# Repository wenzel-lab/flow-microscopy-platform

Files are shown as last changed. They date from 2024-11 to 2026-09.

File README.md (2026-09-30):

# Rio, the open-source flow microscopy platform
Our open hardware flow microscopy platform "Rio Platform" is a more comprehensive version of our open-source [strobe-enhanced microscopy stage](https://github.com/wenzel-lab/strobe-enhanced-microscopy-stage) (build instructions [here](https://wenzel-lab.github.io/strobe-enhanced-microscopy-stage/)), including the control of pressure, flow and temperature in 4-channels. The platform is controlled by ["Rio", our modular microfluidics controller](https://github.com/wenzel-lab/modular-microfluidics-workstation-controller) boards and firmware. Working with pressurised gas, regulators, and flow sensors allows for a compact, faster, and more precise flow control compared to syringe pumps, such as our [3D printed syringe pumps with controller](https://github.com/wenzel-lab/syringe-pumps-and-controller). In contrast to other open-source platforms and some commercial platforms, our implementation is capable of handling high-pressures (up to 6 bar) in order to process gels and more viscous liquids.

Follow us! [#twitter](https://twitter.com/WenzelLab), [#YouTube](https://www.youtube.com/@librehub), [#LinkedIn](https://www.linkedin.com/company/92802424), [#instagram](https://www.instagram.com/wenzellab/), [#Printables](https://www.printables.com/@WenzelLab), [#LIBREhub website](https://librehub.github.io), [#IIBM website](https://ingenieriabiologicaymedica.uc.cl/en/people/faculty/821-tobias-wenzel)

## Usage

<p align="left">
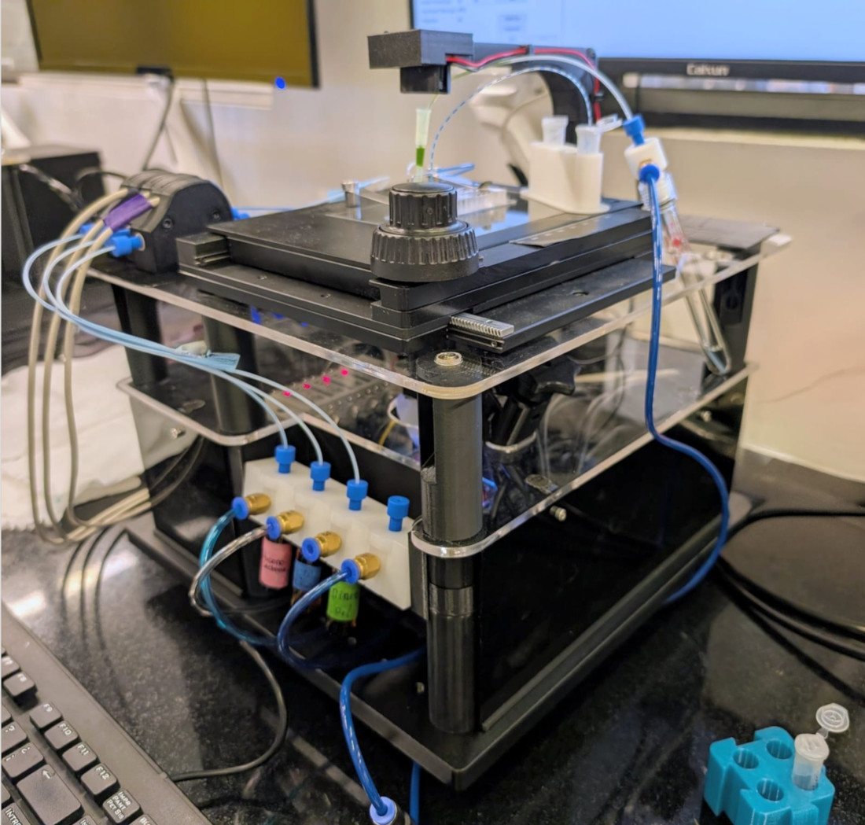
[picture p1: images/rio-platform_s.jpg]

</p>

The platform consists of a number of different functional modules that are connected to each other:
<p align="left">
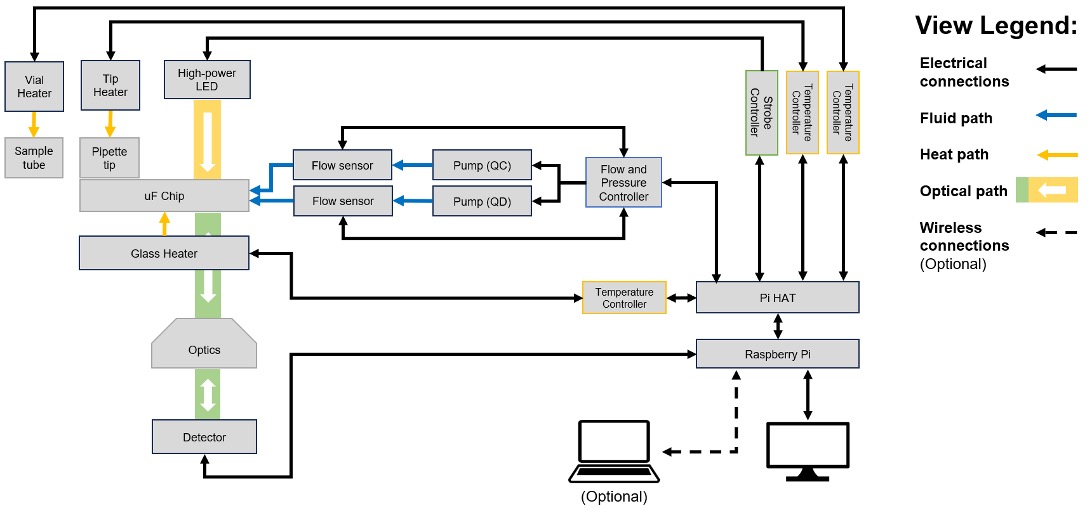
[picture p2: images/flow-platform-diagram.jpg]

</p>

One use of our heater modules is the tip-heater for injecting agarose gel into microfluidic chips:
<p align="left">
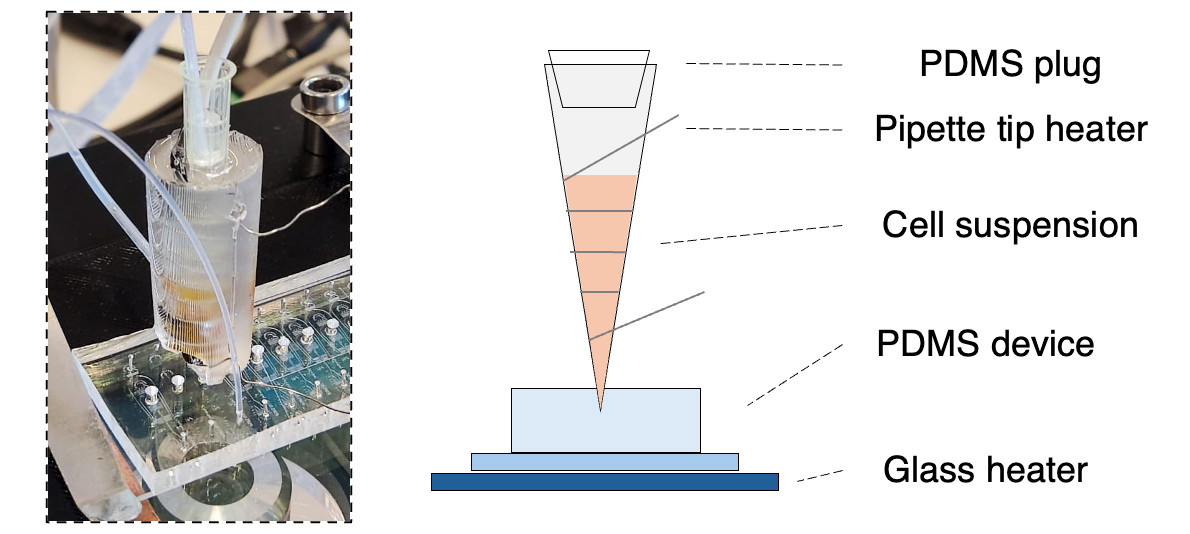
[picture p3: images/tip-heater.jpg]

</p>

We also designed a pressure vial holder with individual manifold caps for easy transfer of samples:
<p align="left">
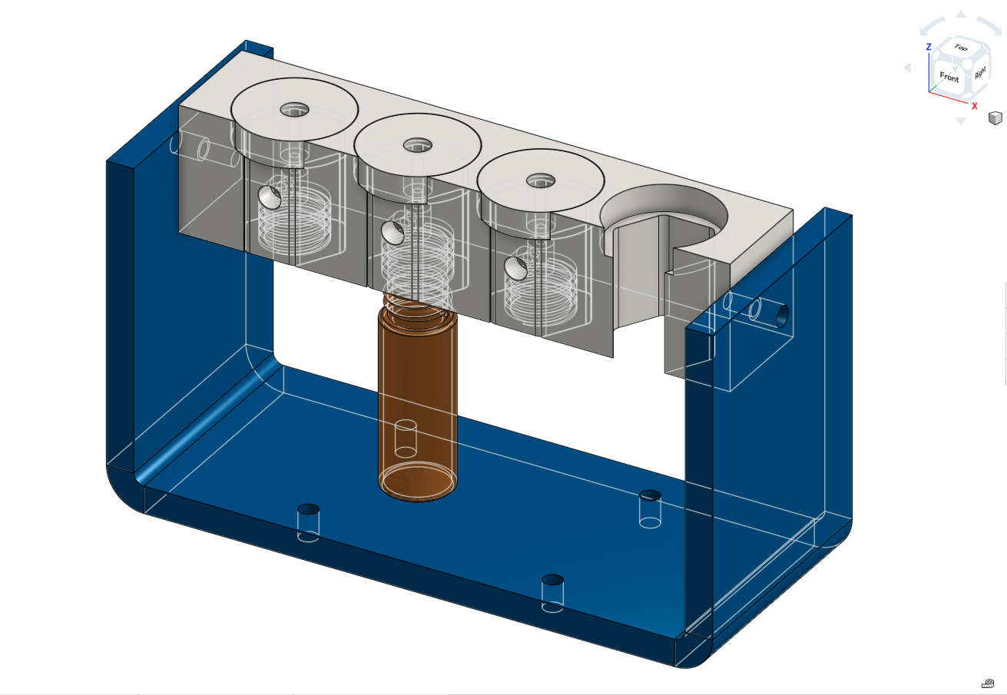
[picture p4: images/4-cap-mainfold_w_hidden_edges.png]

</p>

We also implemented a droplet detection AI module to measure the droplet diameters and display the size distribution https://github.com/wenzel-lab/droplet_AInalysis

## Contribute

You're free to fork the project and enhance it. If you have any suggestions to improve it or add any additional functions make a pull-request or [open an issue](https://github.com/wenzel-lab/flow-microscopy-platform/issues/new).
For interactions in our team and with the community applies the [GOSH Code of Conduct](https://openhardware.science/gosh-2017/gosh-code-of-conduct/).

## Team

+ Project initiators:
    - Tobias Wenzel @MakerTobey
    - Christie Nel @Cyberius
    - Pierre Padilla-Huamantinco @biodotpe
    - Matias Hurtado @matiashl27
+ Contributors:
    - Eduardo Honeyman

## License

[CERN OHL 2W](LICENSE) © Tobias Wenzel, Christie Nel, Eduardo Honeyman, Matías Hurtado, and Pierre Padilla-Huamantinco. This project is Open Source Hardware - please acknowledge us when using the hardware or sharing modifications.

## Funding

This work is part of funded projects granted to T.W. from ANID FONDECYT Iniciacion 11200666, the Chang Zuckerberg Initiative project ‘Latin American Hub for Bioimaging Through Open Hardware’, and CIFAR. Our team is also grateful for the additional funding and resources provided by the [Institute for Biological and Medical Engineering](https://ingenieriabiologicaymedica.uc.cl/en/).

# This project is documented with GitBuilding

## What is GitBuilding

GitBuilding is an OpenSource project for documenting hardware projects with minimal
effort, so you can stop writing and GitBuilding. GitBuilding is a python program that
works on Windows, Linux, and MacOS. More information on the GitBuilding project, or how
to install GitBuilding please see the [GitBuilding website](http://gitbuilding.io)

## How do I edit the documentation?

To edit the documentation you do not need to install anything, the documentation files can
be opened in a plain text editor such as Windows Notepad, Notepad++, gedit, VS Code, etc.
We recommend installing GitBuilding to preview any changes to the documentation.
GitBuilding also comes with a browser-based editor that has a live display of the final HTML documentation.

If you have ever used [markdown](https://www.markdownguide.org/basic-syntax/) you will
notice that the files you are editing are markdown files. GitBuilding uses an extended
markdown syntax (that we call BuildUp). This allows you to keep track of parts in the
documentation. More detailed documentation is available on the
[GitBuilding website](https://gitbuilding.io).

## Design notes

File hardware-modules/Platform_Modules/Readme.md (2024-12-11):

## Organization Modules 
Here you can find information about the different modules created to organize the flow microscopy platform, 3D files are all free accces on Onshape [here](https://cad.onshape.com/documents/959fee0bf6a5bfe78f1dda97/w/e657b641acef5b36bf9099ee/e/20e65f96ae81a38be57a4961)

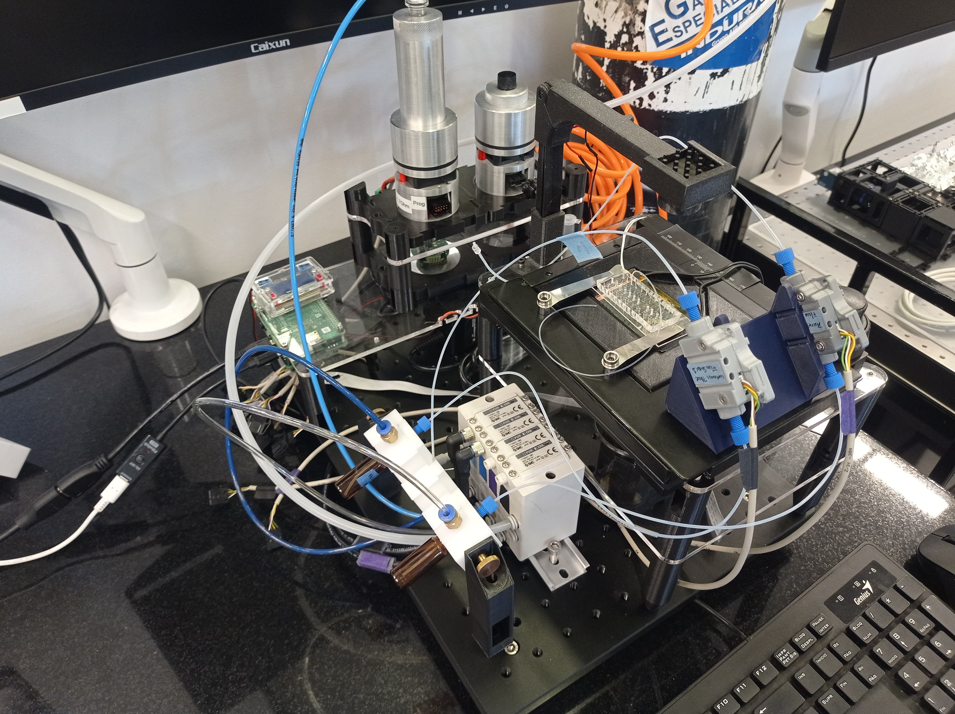
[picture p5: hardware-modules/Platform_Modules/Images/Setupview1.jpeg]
 
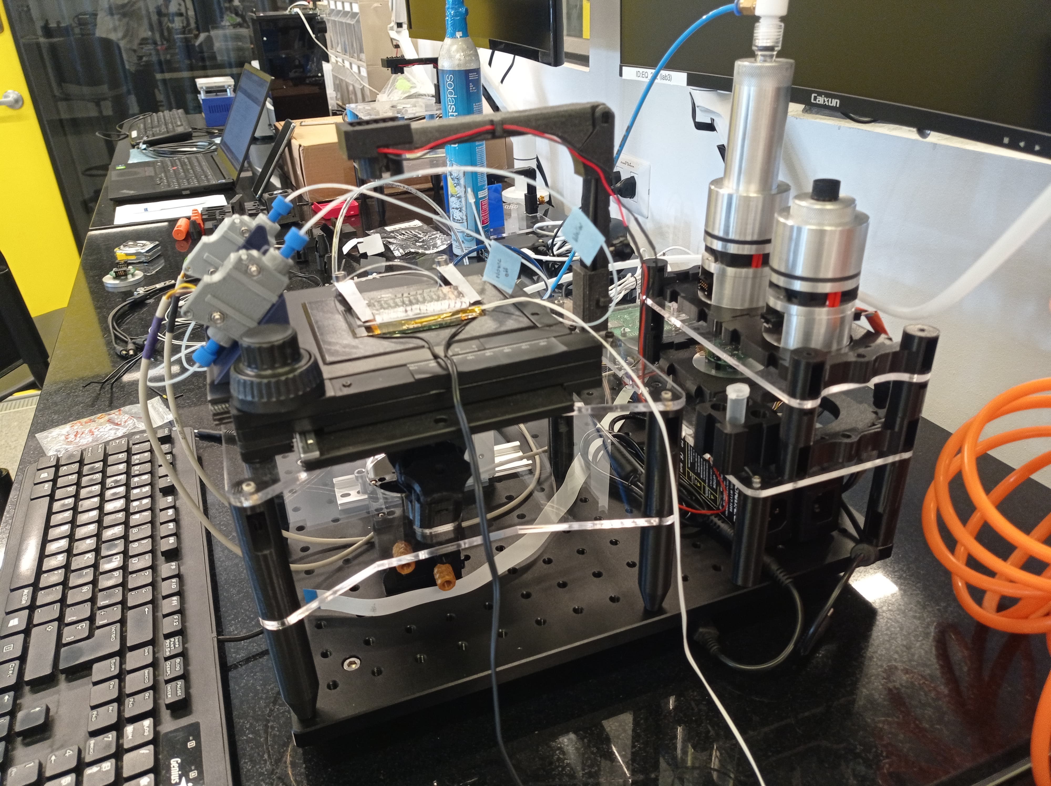
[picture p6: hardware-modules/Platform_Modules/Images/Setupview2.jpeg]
 

From the analysis of the state of the microscopy platform without a clear method of organization eight crucial modules were identified:
- Pressure module
- Flow module
- Vial heat and stir module
- Glass heater module
- Tip heater module
- High-speed imaging module 
- Vial holder module 
- Electronic control module
  
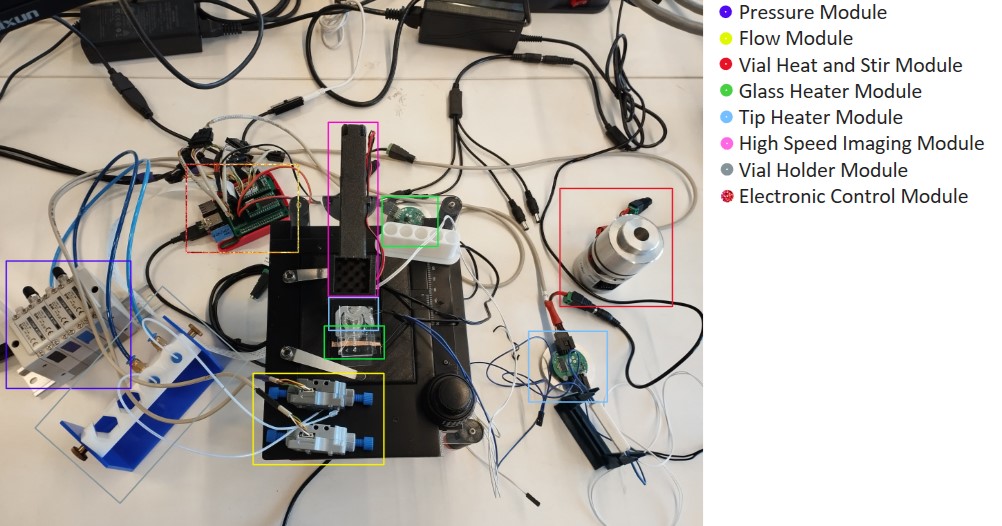
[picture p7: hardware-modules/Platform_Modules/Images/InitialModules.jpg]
 

In that state, all the modules were using an unreasonable amount of space in the science lab, therefore the objective of adapting them to an enclosed space and improving the organization and clustering of cables while maintaining the functionality of the system was established. To direct this process the established area was limited by an optic table with dimensions of 30 by 40 centimeters, which was purchased [here](https://es.aliexpress.com/item/1005005133684496.html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). The reason to use this table is that it allows for an easier fixing of the elements to it do to the high weight and screwable surface.

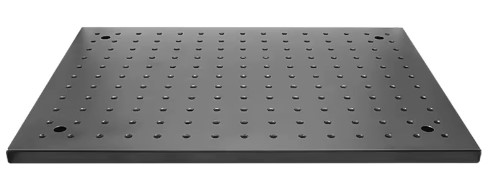
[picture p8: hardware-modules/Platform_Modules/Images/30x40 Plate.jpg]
 

From the eight initial modules we decide on reducing them to five by joining the modules that benefit for beeing closer together, resulting in this first iteration.

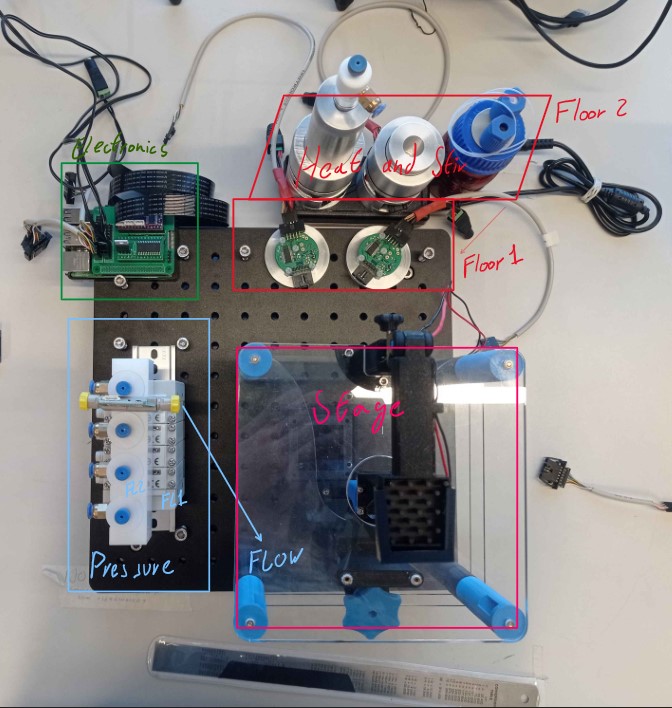
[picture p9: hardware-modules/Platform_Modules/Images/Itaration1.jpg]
 

From further iteration on this model we got to the final optimal organization moduls that you can find with greater detail here:
- [Brain Module (Electronics)](Brain_Module/Readme.md)
- [Heat and Stir Module](Heat_Stir_Module/Readme.md)
- [Pressure Regulator Module](Pressure_Module/Readme.md)
- [Flow Sensor Module](Flow_Module/Readme.md)
- [Stage Module](Stage_Module/Readme.md)

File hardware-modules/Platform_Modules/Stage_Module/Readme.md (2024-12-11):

## Microscopy Stage Module

This includes all the components that conform to the microscopy stage, like the microscope, movements stage, stage legs, and leg adaptors for the optic table

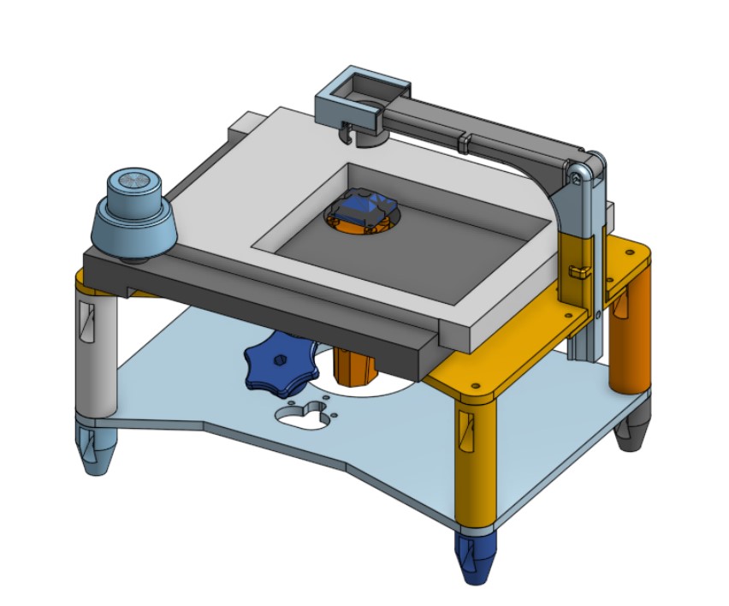
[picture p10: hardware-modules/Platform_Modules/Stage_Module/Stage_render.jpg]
 
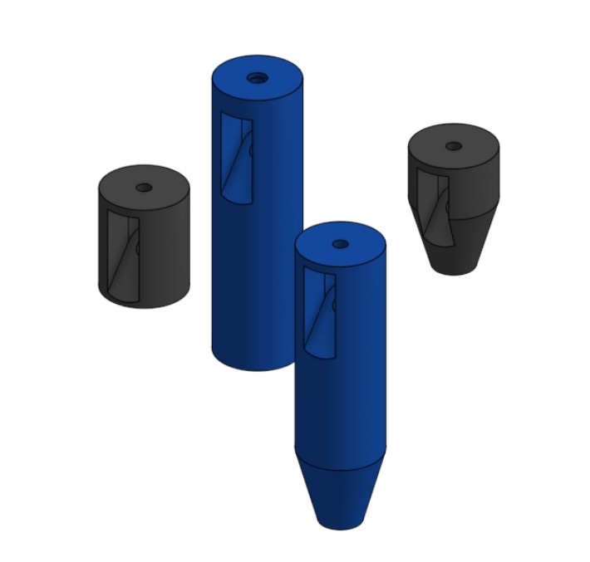
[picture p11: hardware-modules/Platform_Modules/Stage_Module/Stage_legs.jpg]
 
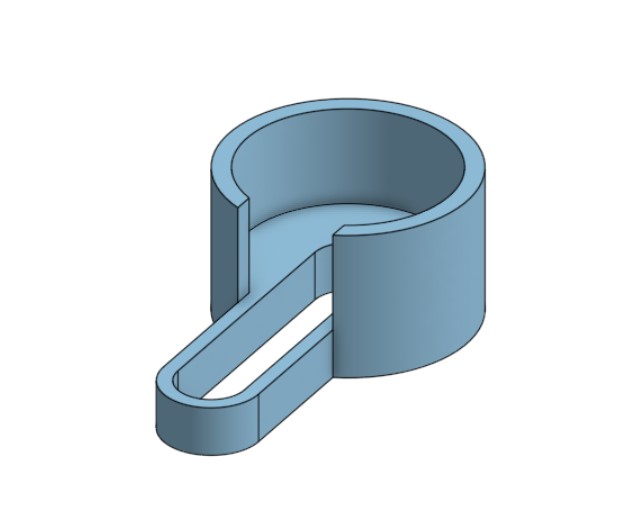
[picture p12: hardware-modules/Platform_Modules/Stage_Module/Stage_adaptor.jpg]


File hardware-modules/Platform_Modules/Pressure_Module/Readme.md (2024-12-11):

## Pressure Regulator Module

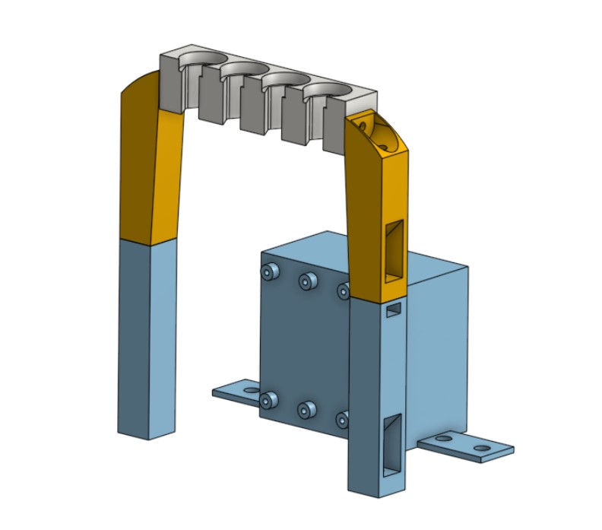
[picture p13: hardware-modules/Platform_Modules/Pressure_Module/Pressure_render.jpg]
 

One of the crucial components when it comes to microfluidics experimentation is the correct management of the pressure of the fluids, for this a pressure regulator is needed

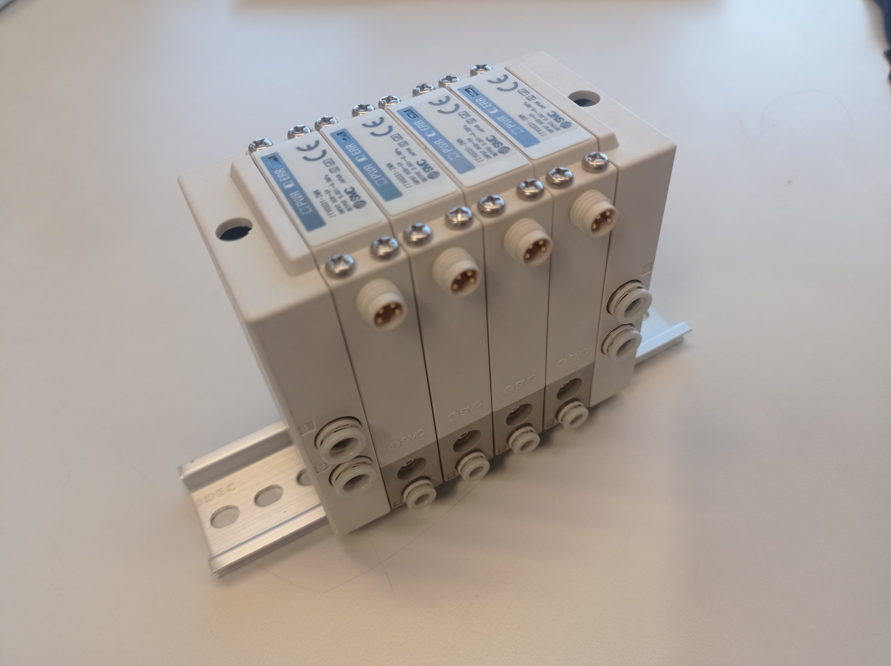
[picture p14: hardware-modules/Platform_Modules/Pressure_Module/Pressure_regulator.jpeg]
 

This regulator connects directly to the fluid samples that in the early unorganized state were held by the sample reservoir you can find [here](flow-microscopy-platform/module_sample_reservoirs/Readme.md).

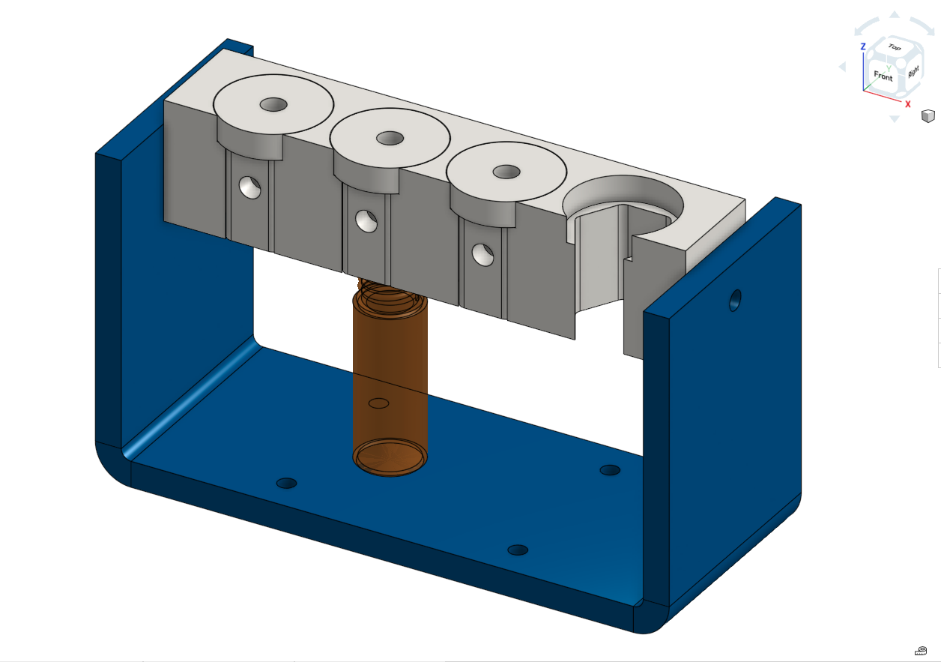
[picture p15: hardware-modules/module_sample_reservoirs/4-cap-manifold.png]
 

To accommodate the regulator and the samples in the newly organized setup the first step was allowing them to be closer to each other and reduce the need for unnecessary tubings between them. To prevent the reservoirs from crashing with the regulator new legs for de sample reservoir were designed allowing to modularly change of the height of the holder depending on the position of the regulator another component of the microscopy stage.

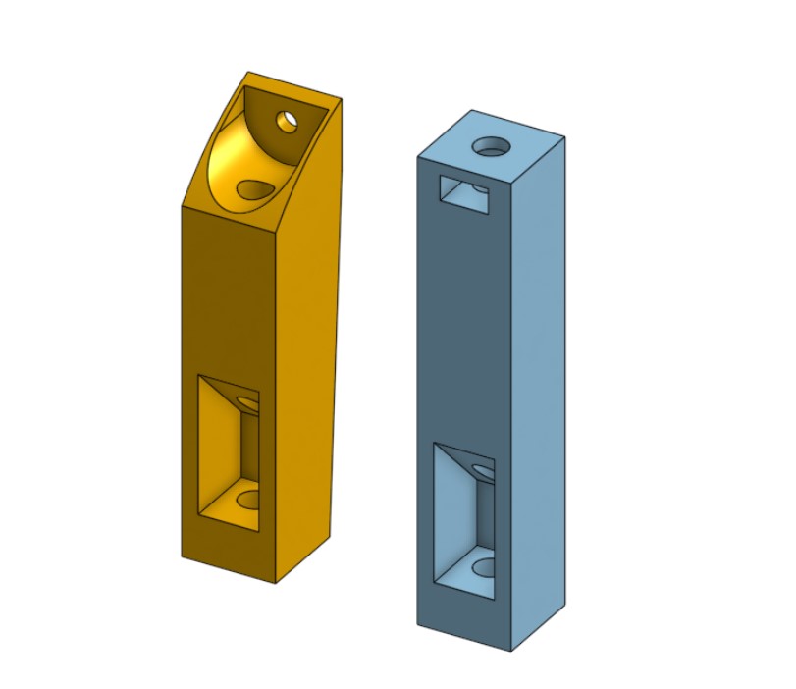
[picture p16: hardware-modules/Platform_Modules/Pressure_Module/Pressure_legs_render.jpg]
 
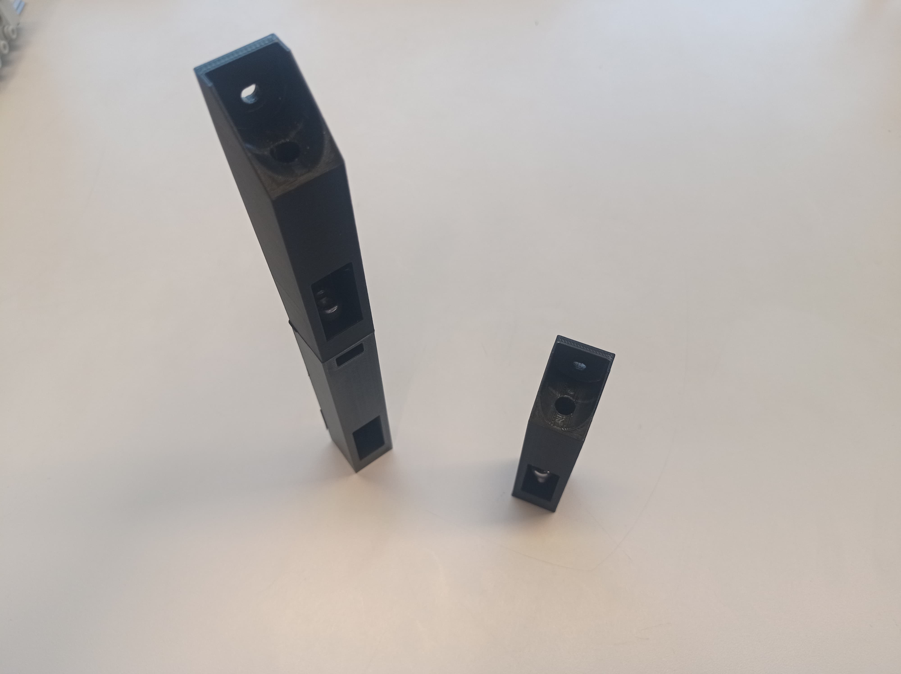
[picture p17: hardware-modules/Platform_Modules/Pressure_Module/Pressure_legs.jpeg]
 
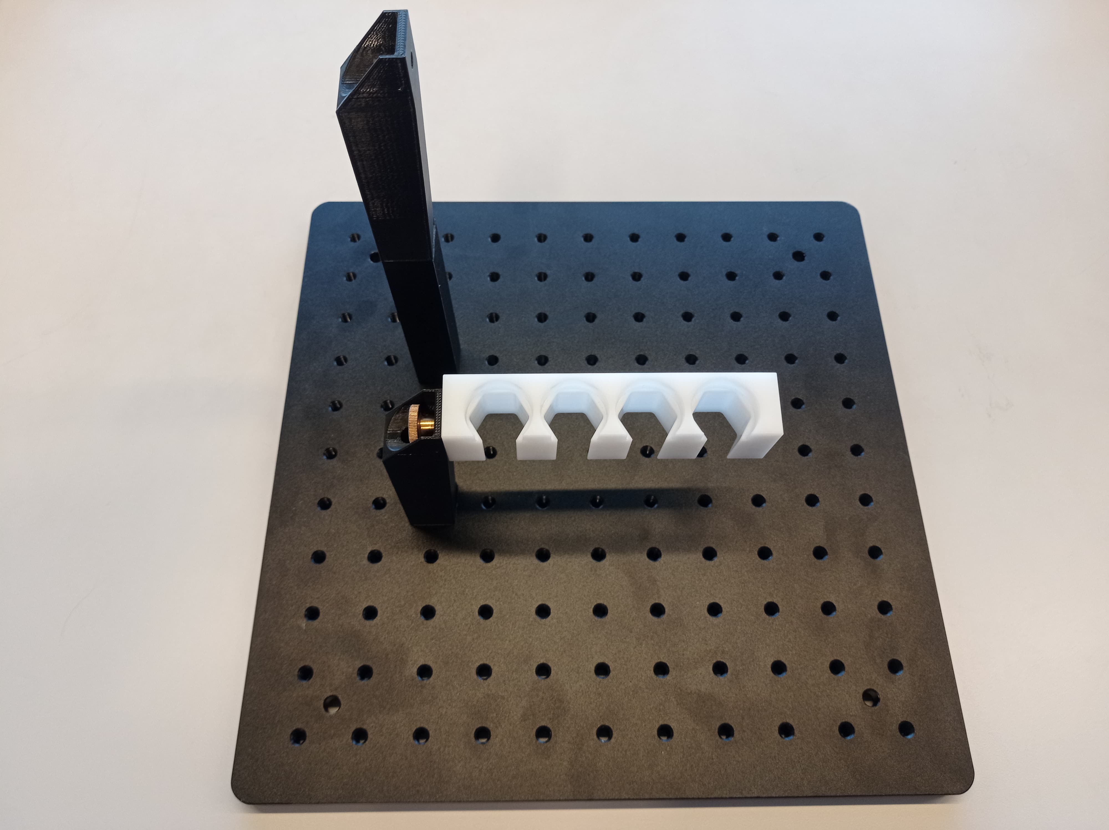
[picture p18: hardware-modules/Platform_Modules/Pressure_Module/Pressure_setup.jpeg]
 

both the new legs and the regulator allow for a simple M6 screw to hold them onto the optic table but a screw and nut are needed for the extra levels of the legs

### Future Steps
- Is in discussion the need to use an external component to hold the vials and as a possibility using lacer cuts to hold the samples onto the plates of the microscope is a viable option
- The use of longer legs is determined by the height of the position of the flow controllers and is possible to need adjustments if the position of the flow controller changes
- The regulator is optimal to be closer to the samples but it's not completely necessary for both to be in the same vertical position and there is room to improve on changing the horizontal angle between these two components

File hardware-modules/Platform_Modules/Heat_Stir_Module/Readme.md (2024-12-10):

## Heat and Stear Module
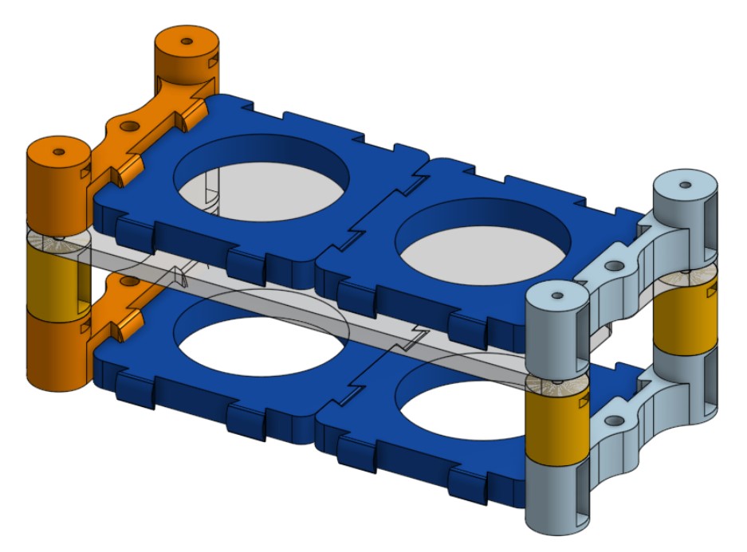
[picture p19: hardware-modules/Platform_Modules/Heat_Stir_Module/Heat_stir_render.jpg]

For instance, the microfluid stage needs to be heated or the sample needs to be stared while kept warm, for this there is the need for 2 heaters and stirring components.

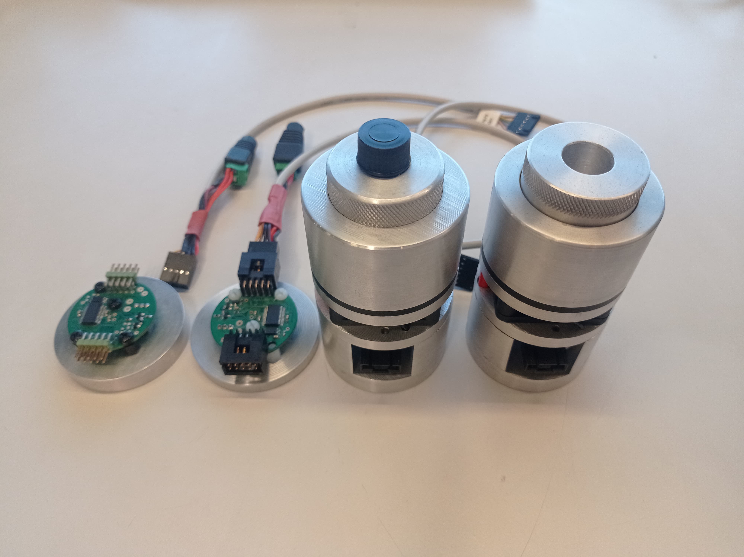
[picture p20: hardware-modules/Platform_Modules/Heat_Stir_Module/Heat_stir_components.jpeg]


These components share the same base, a 5.5 cm diameter metal plate, for this a modular system that allows these 4 components to be enclosed together while minimizing space was implemented. This works with base pillars that have a design compatible with the [Modular Tube Holders](https://www.printables.com/model/514591-moldular-tube-holders) used by LibreHub, and that using the same stage legs from the microscopy stage allows for the assembling of multiple  floors  using an acrylic plate of 5 or 6 mm as support.

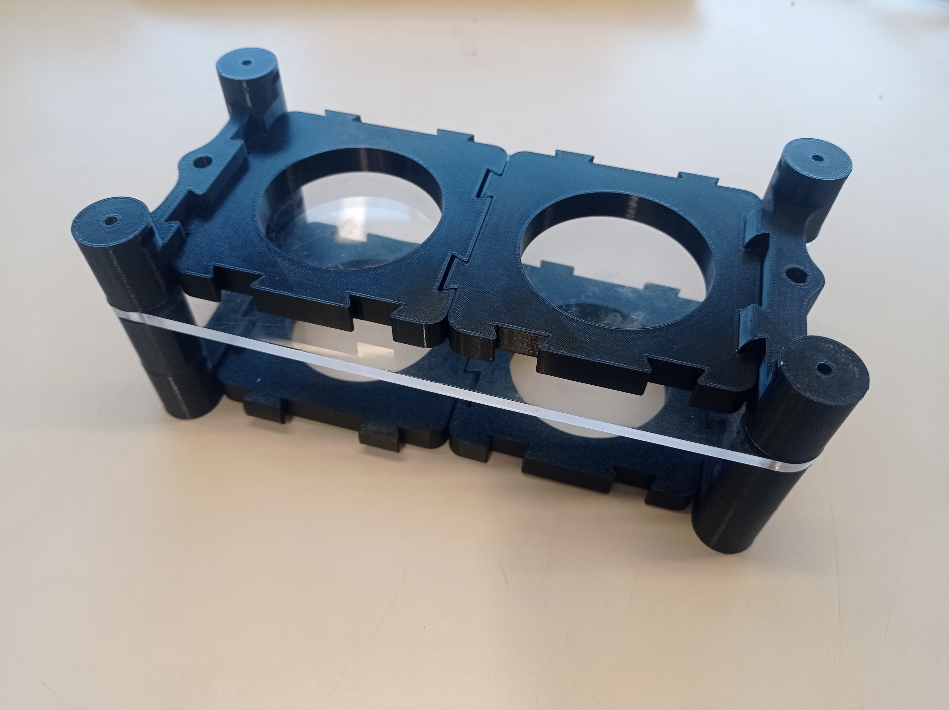
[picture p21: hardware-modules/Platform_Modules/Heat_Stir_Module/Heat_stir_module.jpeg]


This module can be set up on top of the [Brain module](Platform_Modules/Brain_Module/Readme.md) connecting the stage legs or set up directly onto the optic table using the corresponding M4 screws

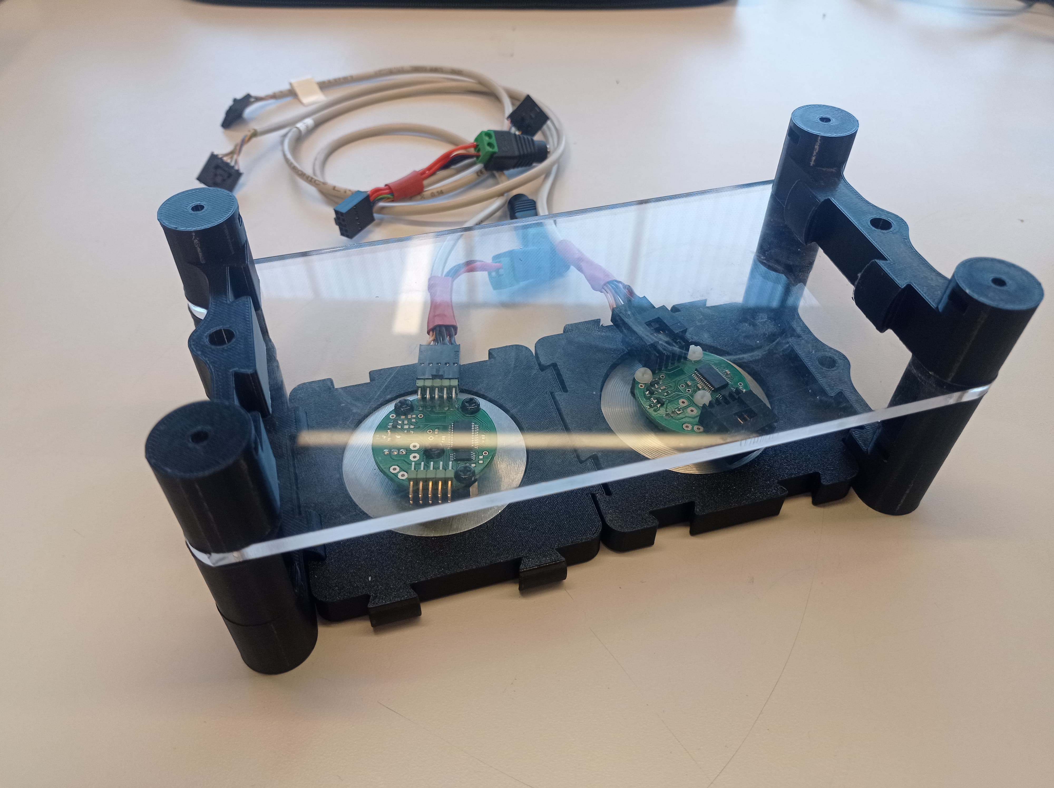
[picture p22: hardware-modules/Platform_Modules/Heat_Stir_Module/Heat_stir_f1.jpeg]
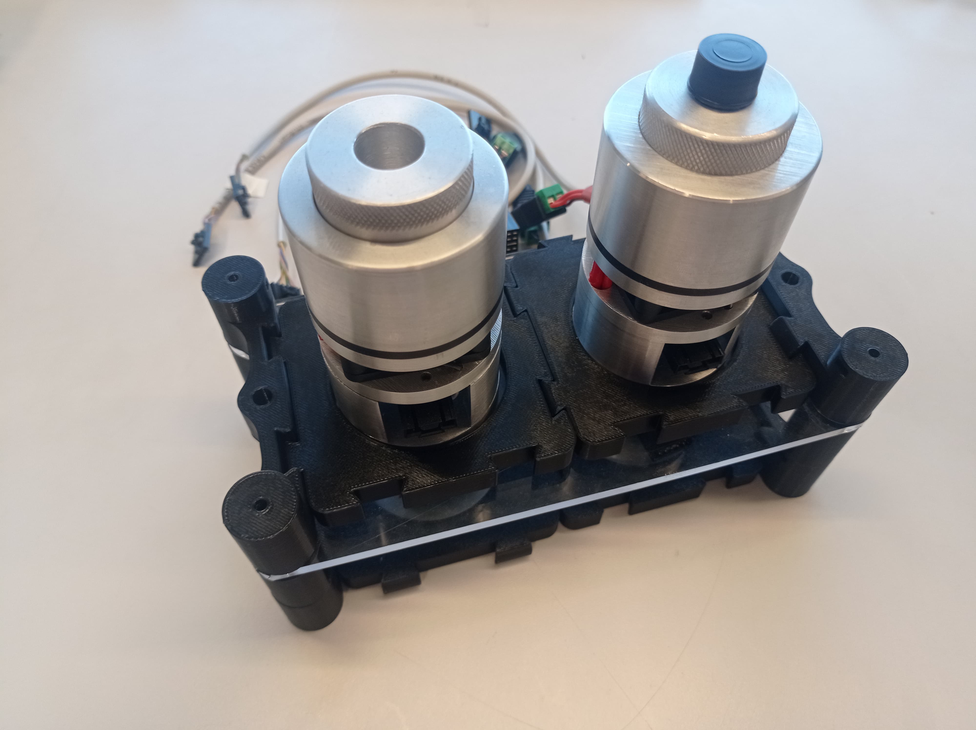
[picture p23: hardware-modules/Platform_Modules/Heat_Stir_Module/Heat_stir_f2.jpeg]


### Future Steps:
- The height of this stage could be modified so the second floor is on the same level as the microscopy stage
- Because the brain stage was designed later there is space on the surface of it that could be used by extending the bases of this module and allowing for extra tube holders

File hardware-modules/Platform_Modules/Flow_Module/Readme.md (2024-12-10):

## Flow Sensor Module
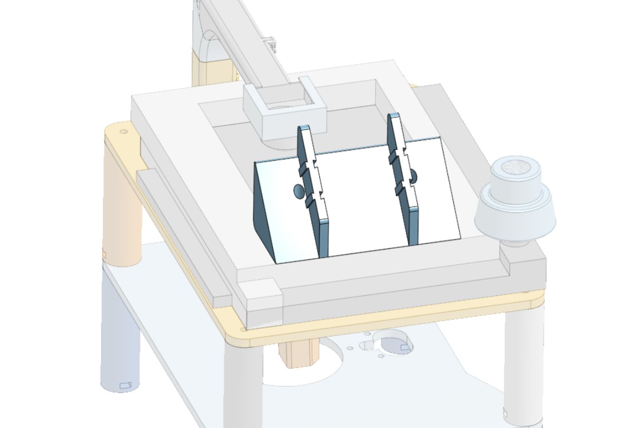
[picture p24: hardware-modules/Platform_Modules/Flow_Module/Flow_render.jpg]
 

This module consists of a 3D printed holder for the flow controllers whose objective is to keep the controllers still and close to the microchip of microfluidics allowing the tubings that run in between them to not be altered and as benefits shorten the time of travel from controller to chip.

The holder module is designed to be compatible with the flow controller casing previously designed to protect them. Working with a slide mechanism allows for easy handling of the flow controllers while maintaining a firm grip on them. this puts together is meant to be screwed into a metal [x-y movement system](link to stage module or web page of the system) using short M2 screws, this movement system is mounted to the microscopy stage to improve the observation of samples, more details [here]("Platform_Modules/Stage_Module/Readme.md")

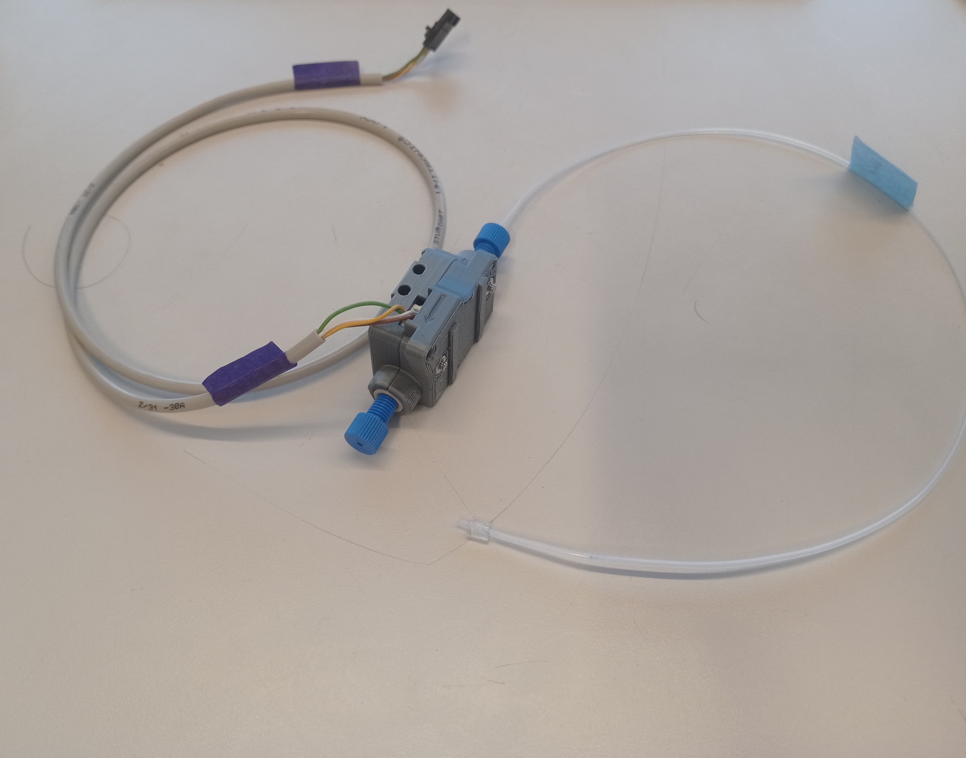
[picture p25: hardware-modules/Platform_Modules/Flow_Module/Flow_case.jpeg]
 
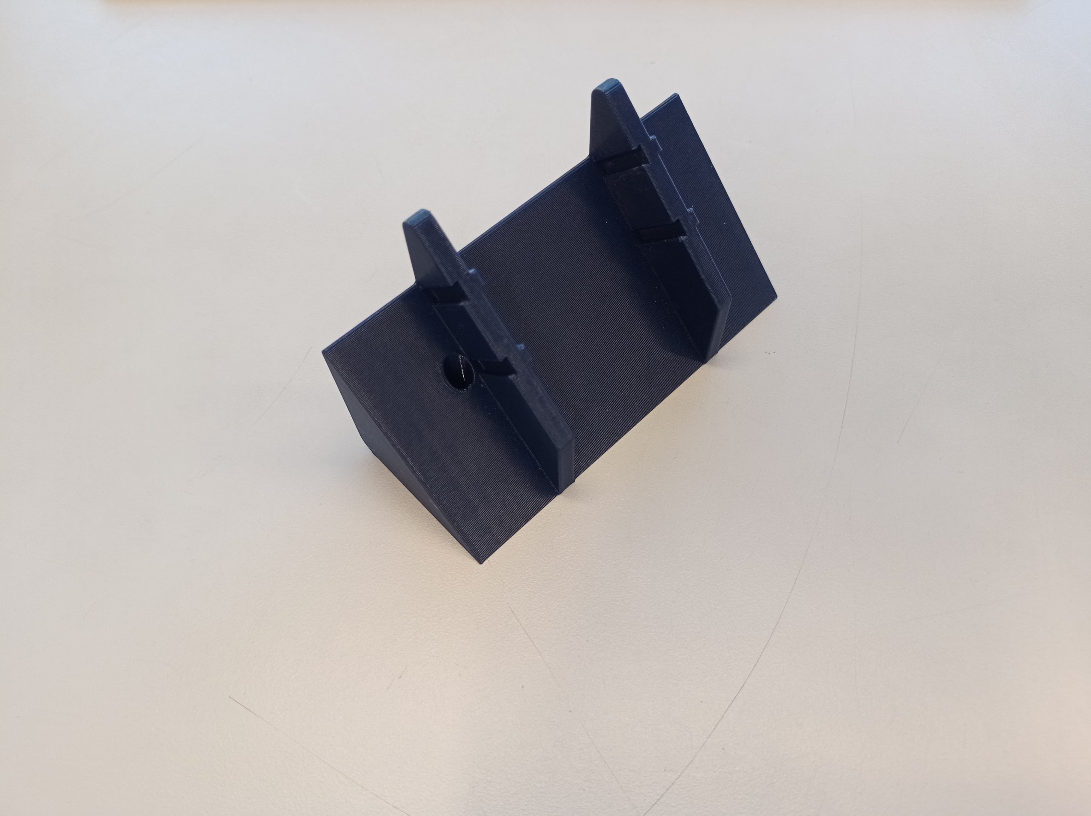
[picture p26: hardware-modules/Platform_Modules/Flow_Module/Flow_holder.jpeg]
 
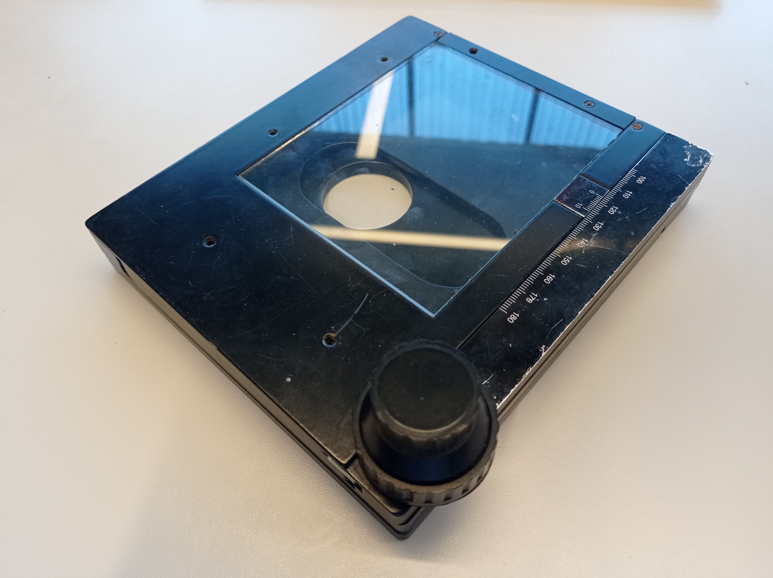
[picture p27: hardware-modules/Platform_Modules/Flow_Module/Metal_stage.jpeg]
 
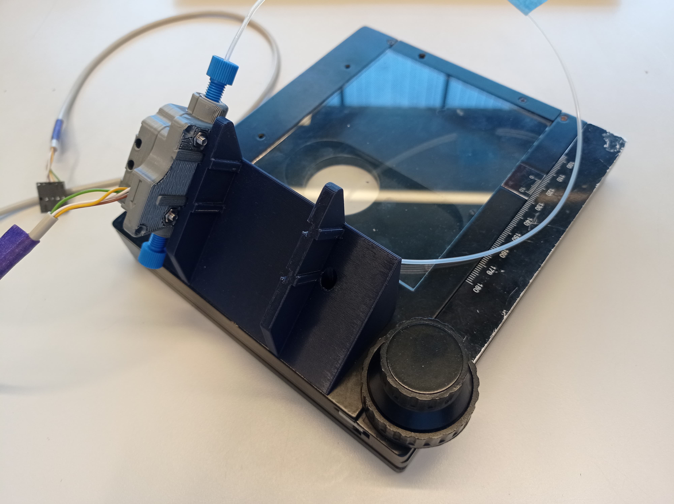
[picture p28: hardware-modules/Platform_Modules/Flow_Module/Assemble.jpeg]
 

### Future Steps
- The holder was tested on a horizontal position but proved not efficient for being too close to the microchip, the angle of inclination of the holder could be adjusted to improve on this
- At the moment to screw the holder 1 cm long m2 screws are needed with 2 spacers, the model could be changed so spacers aren't needed

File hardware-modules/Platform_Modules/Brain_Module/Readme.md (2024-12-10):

## Brain Module (Electronics)
 

This module consists of an acrylic five-millimeter plate that serves as the base for the [Heat and Stir Module](/Platform_Modules/Heat_Stir_Module/Readme.md) while also holding and protecting the main electronic component, the [Raspberry Pi](addlink_to_info_of_rasp) and the power supplies. As support, it uses previously designed seven centimeters stage legs screwed in with M3 screws and nuts.

### Module Plate
 

Complementary to this two different cable holders were designed to facilitate the organization of the cables coming out of the raspberry that can be grouped into two distinct types, the power adaptor and the Molex adaptor (in the name of the cable type). Both of these consist of two 3D printed parts that clamp the cables using four 1.1 centimeters round magnets

### Power Adaptor
With this adaptor, the majority of the power cables can be tucked away under the optic table and only have the adaptor show from the back


 

### Molex Adaptor


 

### Future Steps
- Define if the main plate needs to change to heat insert or maintain screws and nuts
- Design a way to keep the power supplies fixed under the main plate
- Improve on the adaptors to make the magnets not visible and less easy to remove

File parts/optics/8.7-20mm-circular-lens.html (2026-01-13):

# Strobe-enhanced microscopy stage

by Pierre Padilla-Huamantinco, Matías Hurtado-Labarca, and Tobias Wenzel

Latin American Hub for Bioimaging Through Open Hardware (LIBRE hub)

# 8.7° 20mm Circular Beam Optics



Suppliers:

- Luxeonstar / Lens (https://www.luxeonstar.com/carclo-8.7-degree-20mm-optic)
- Luxeonstar / Holder (https://www.luxeonstar.com/carclo-20mm-round-optic-holder-black)

GitBuilding logo Documentation powered by GitBuilding (https://gitbuilding.io)

©2023 Pierre Padilla-Huamantinco, Matías Hurtado-Labarca, and Tobias Wenzel

Contact: librehub@uc.cl

Strobe-enhanced microscopy stage is released under CERN-OHL-S-2.0.

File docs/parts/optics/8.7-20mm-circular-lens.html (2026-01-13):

# Flow Microscopy Platform

by Pierre Padilla-Huamantinco, Juan León-Gutierrez, Matias Hurtado-Labarca, and Tobias Wenzel

Institute for Biological and Medical Engineering, Pontificia Universidad Católica de Chile

# 8.7° 20mm Circular Beam Optics



Suppliers:

- Luxeonstar / Lens (https://www.luxeonstar.com/carclo-8.7-degree-20mm-optic)
- Luxeonstar / Holder (https://www.luxeonstar.com/carclo-20mm-round-optic-holder-black)

GitBuilding logo Documentation powered by GitBuilding (https://gitbuilding.io)

©2026 Pierre Padilla-Huamantinco, Juan León-Gutierrez, Matias Hurtado-Labarca, and Tobias Wenzel

Contact: tobias.wenzel@uc.cl

Flow Microscopy Platform is released under CERN-OHL-1.2.

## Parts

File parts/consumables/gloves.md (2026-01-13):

# Nitrile gloves

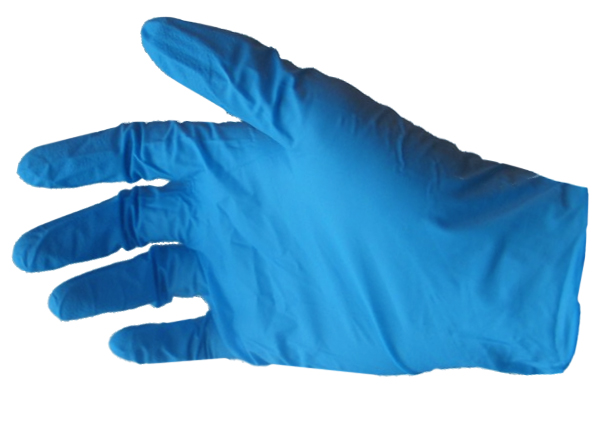
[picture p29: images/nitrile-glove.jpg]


They safeguard sensitive electronic components from contamination, oils, and static discharge.

These gloves prevent potential damage during assembly, repair, or handling of electronic devices.

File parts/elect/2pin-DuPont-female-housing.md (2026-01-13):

# 2 pin Du Pont Female Housing

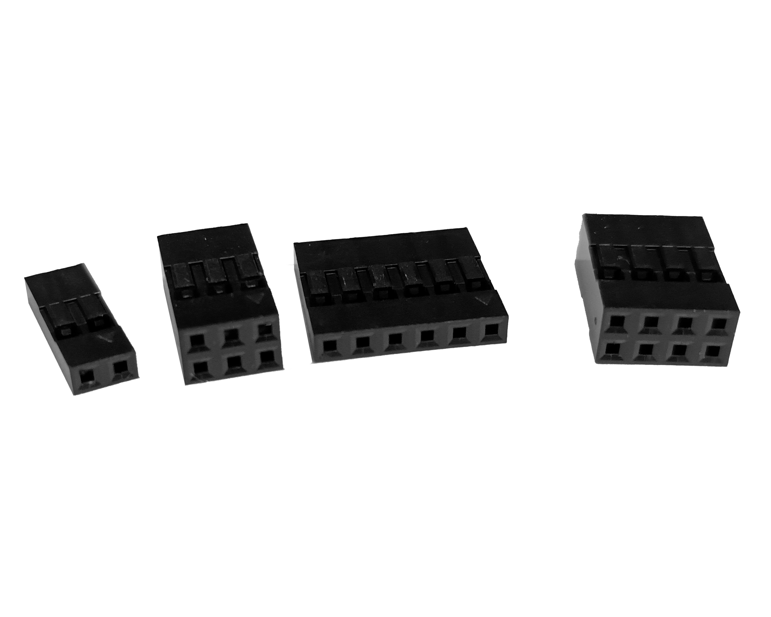
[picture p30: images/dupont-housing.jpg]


Plastic connector designed to hold and secure two male Dupont pins.
It provides a housing for wire connections, allowing for organized and reliable electrical connections.
These housings are commonly used in electronics and prototyping to create secure and structured wiring setups.

_Supplier:_ [Hubot](https://hubot.cl/producto/kit-620-conectores-dupont-254-mm-m-h-sku-425f1/)

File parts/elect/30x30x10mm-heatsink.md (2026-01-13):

# 30x30x10mm Heat Sink

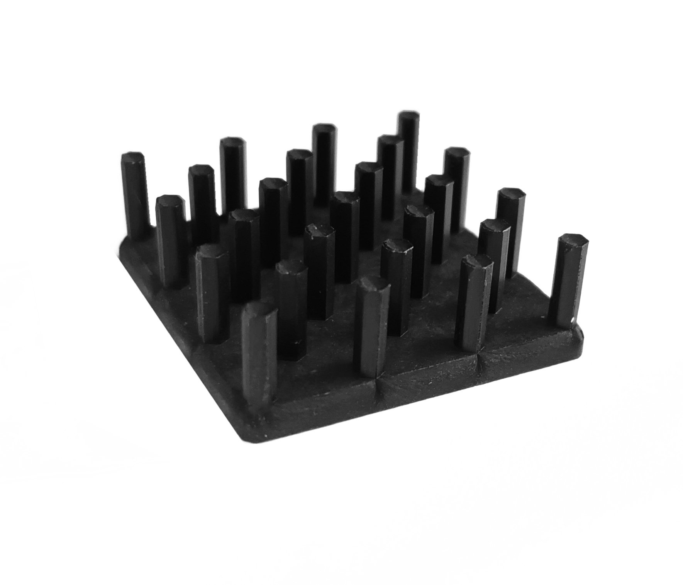
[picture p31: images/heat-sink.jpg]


Passive cooling component used to dissipate heat from electronic devices. Commonly used in computers, LED lights, and other electronic devices to prevent overheating and ensure proper functioning.

_Supplier:_ [Luxeonstar](https://www.luxeonstar.com/30mm-square-14.0-degree-cw-alpha-heat-sink)

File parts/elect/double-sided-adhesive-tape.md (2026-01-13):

# Double-sided Adhesive Tape

Adhesive coatings on both sides for joining surfaces.
It's widely used in bonding applications, eliminating the need for visible fasteners.
This tape is commonly utilized in crafting, construction, and packaging for discreet and secure adhesion.

_Supplier:_ [Luxeonstar](https://www.luxeonstar.com/mounting-tape-for-carclo-20mm-round-optic-holders)

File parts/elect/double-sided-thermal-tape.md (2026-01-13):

# Double-sided Thermal Tape

Tape with adhesive on both sides, specifically designed for transferring heat between two surfaces.
It is commonly used to attach heat sinks or cooling components to electronic devices for effective heat dissipation.
This tape ensures efficient thermal management in applications such as electronics, computers, and LED lighting.

_Supplier:_ [Luxeonstar](https://www.luxeonstar.com/pre-cut-thermal-tape-for-20mm-hex-bases-12pcs)

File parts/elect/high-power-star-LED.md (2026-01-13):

# High-power Star LED

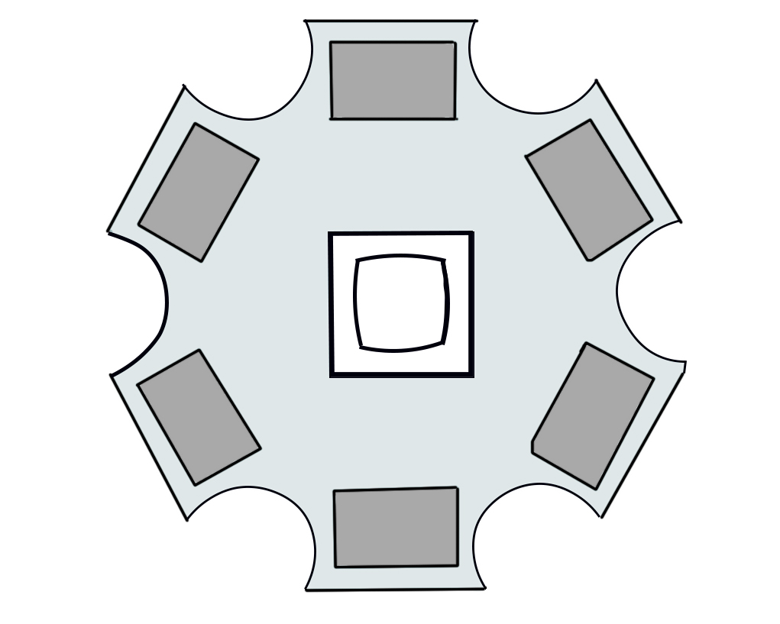
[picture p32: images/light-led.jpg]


Light-emitting diode (LED) with significant luminosity and brightness output.

High-power Star LEDs are known for their efficient energy consumption and long lifespan, making them a popular choice for various illumination needs.

_Supplier:_ [Farnell](https://uk.farnell.com/intelligent-led-solutions/ilh-og01-nuwh-sc221-wir200/led-mod-neutral-wht-4000k-270lm/dp/3583050)

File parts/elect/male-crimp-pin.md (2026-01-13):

# Male Crimp Pin

Small metal connector with a protruding pin.
It is used to terminate a wire and create a secure electrical connection by crimping it onto the wire's end.

Male crimp pins are commonly used in electronics and wiring applications for reliable signal transmission.

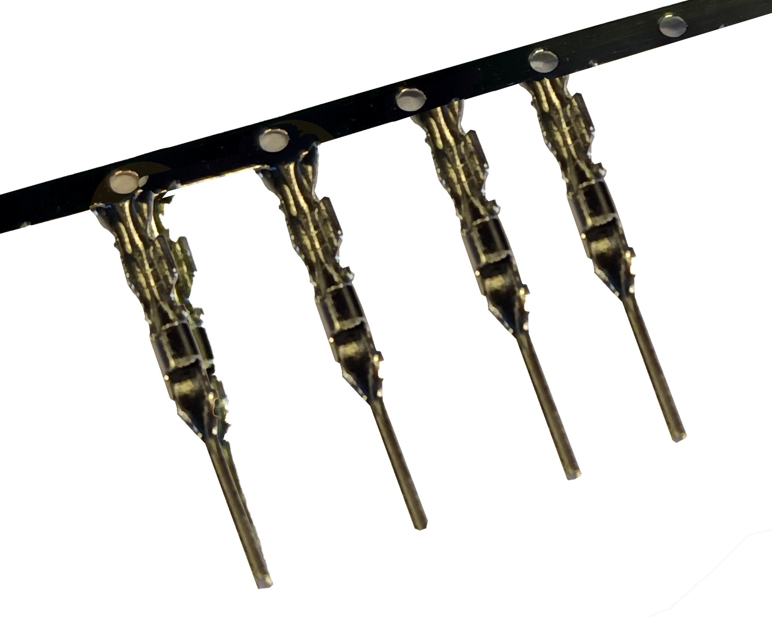
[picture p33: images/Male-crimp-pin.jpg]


_Supplier:_ [Hubot](https://hubot.cl/producto/kit-620-conectores-dupont-254-mm-m-h-sku-425f1/)

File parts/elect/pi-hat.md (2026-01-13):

# Pi Hat
Expansion board designed to fit onto a Raspberry Pi's GPIO pins.
It provides additional functionalities, such as sensors, interfaces, and integrated circuits, to enhance the capabilities of the Raspberry Pi.
HATs are plug-and-play modules, making them easy to use and customize for various projects.

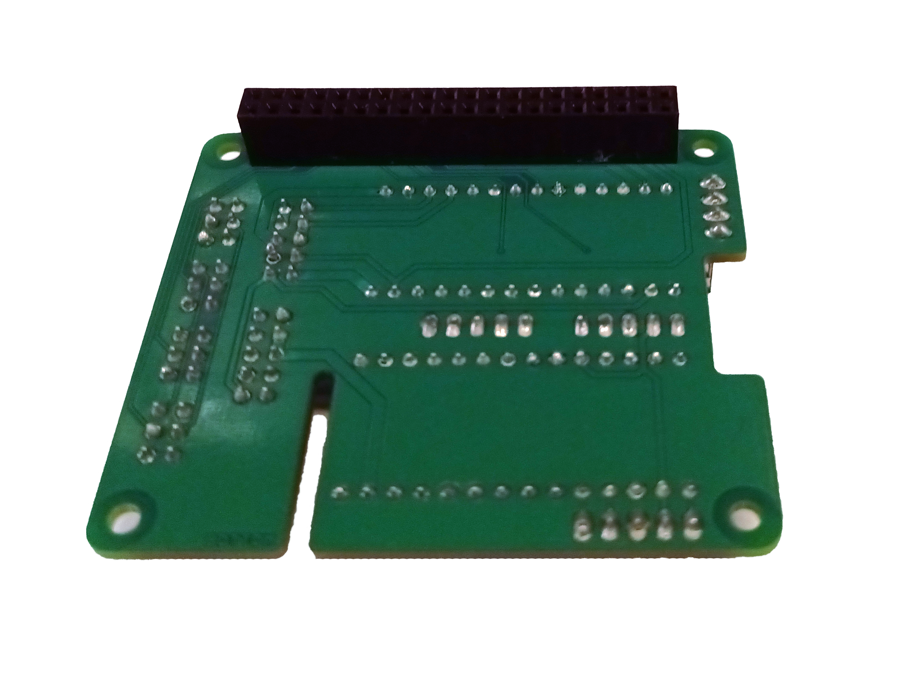
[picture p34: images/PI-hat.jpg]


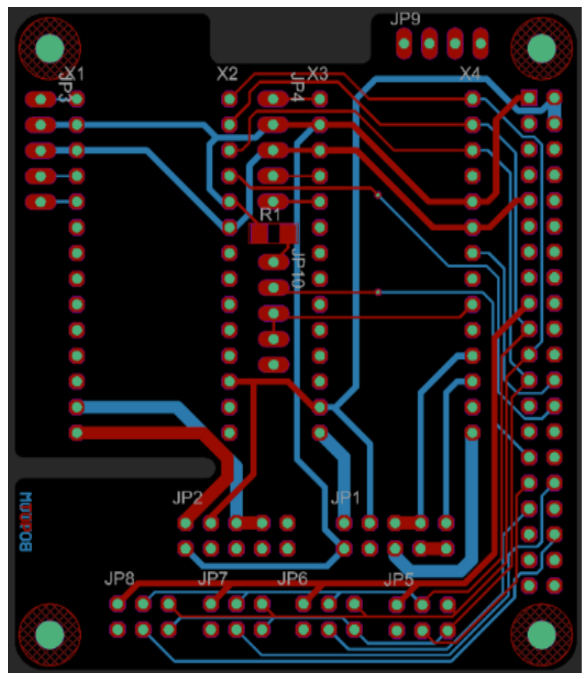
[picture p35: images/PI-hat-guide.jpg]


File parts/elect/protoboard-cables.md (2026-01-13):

# Conductor Flexible Cable

A conductor flexible cable contains multiple strands of conductive material for frequent bending, ensuring reliable connections during movement.

|Attribute |Value |
|--- |-- |
|Color|Red|
|Length|1.7 m|
|AWG|20|
 |Supplier|-[MCI electronics](https://mcielectronics.cl/shop/product/cable-para-protoboard-rojo-10420/)|

|Attribute |Value |
|--- |-- |
|Color|Black|
|Length|1.7 m|
|AWG|20|
 |Supplier|-[MCI electronics](https://mcielectronics.cl/shop/product/cable-para-protoboard-negro-sparkfun-10386/)|

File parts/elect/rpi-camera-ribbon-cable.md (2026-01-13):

# Raspberry Pi camera ribbon cable

Flat, flexible cable with parallel wires, commonly used for internal device connections. It's prevalent in electronics like computers and printers due to its space-saving design. Ribbon cables enable organized and efficient wiring in tight spaces.

In the [Strobe-enhanced microscopy stage](https://wenzel-lab.github.io/strobe-enhanced-microscopy-stage/) case it connects the raspberry pi and the camera.

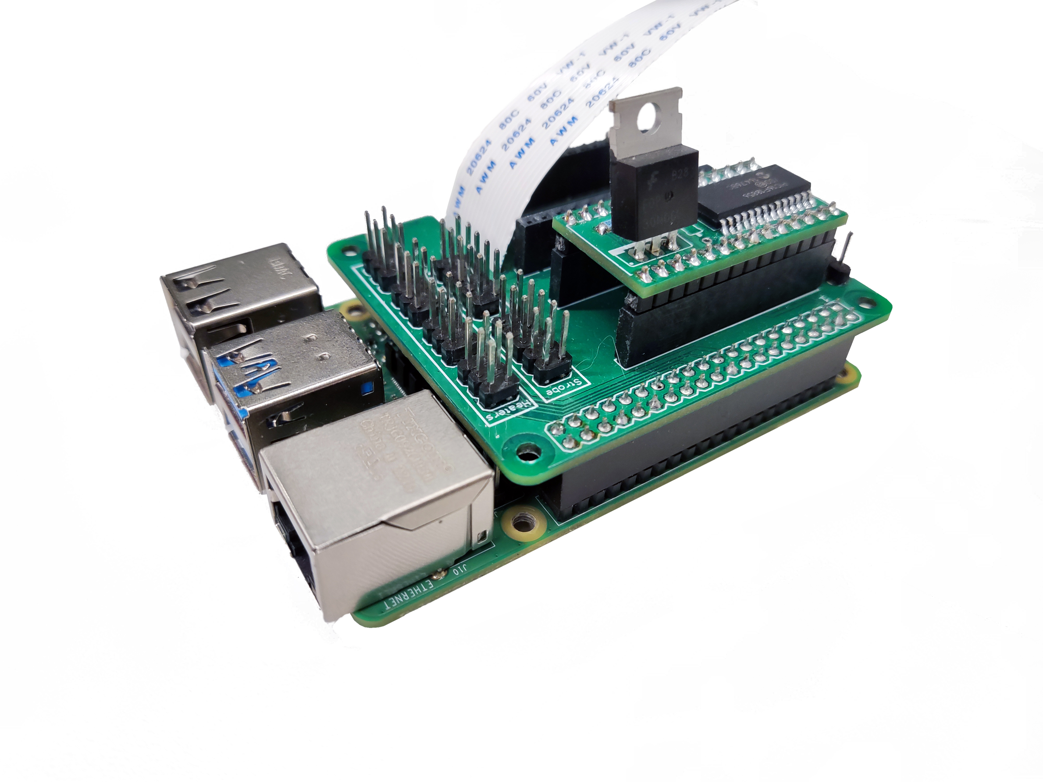
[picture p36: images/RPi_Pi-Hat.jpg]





_Supplier:_ [MCI electronics](https://mcielectronics.cl/shop/product/cable-flexible-para-camara-o-pantalla-raspberry-pi-610mm-25034/)

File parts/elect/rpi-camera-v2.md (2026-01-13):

# Raspberry Pi camera V2

Official camera module designed for Raspberry Pi boards.
It features a high-quality image sensor and a lens with adjustable focus.


_Supplier:_ [MCI electronics](https://mcielectronics.cl/shop/product/camara-v2-para-raspberry-pi-raspberry-pi-21481/)

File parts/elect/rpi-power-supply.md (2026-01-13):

# Raspberry Pi Power Supply



A Raspberry Pi power supply provides a stable voltage, typically 5 volts.
It ensures proper device operation by delivering the required power.

_Supplier:_ [MCI electronics](https://mcielectronics.cl/shop/product/transformador-usb-tipo-c-5v-3a-original-para-raspberry-pi-4-raspberry-pi-26718/)

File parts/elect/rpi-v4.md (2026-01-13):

# Raspberry Pi V4

Raspberry Pi is a compact and affordable computer capable of running various operating systems.
It offers GPIO pins for hardware interfacing and supports a wide range of applications, from basic computing tasks to DIY electronics projects and learning programming.



Supplier: [MCI electronics](https://mcielectronics.cl/shop/product/raspberry-pi-4-modelo-b-4gb-ram-raspberry-pi-26710/)

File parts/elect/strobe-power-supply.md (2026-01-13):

---
PartData:
    Specs:
        Type: Charger
        Output: 5V-3A
        Model: "0530"
        Cable length: 110cm
        Supplier: -[Altronics](https://altronics.cl/power-supply-5v-3A-21x55)
---
# Strobe Power Supply




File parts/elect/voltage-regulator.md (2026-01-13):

# Voltage Regulator
It is used to control manually exactly how many electricity circulates. 



_Supplier:_ [AFEL](https://afel.cl/producto/regulador-de-voltaje-step-down-dc-dc-lm2596-con-voltimetro/)

>! In some models, the electronics of this can be exposed, be sure to cover them to avoid possible accidents.

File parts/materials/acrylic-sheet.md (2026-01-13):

# Acrylic sheet
5mm thick plates.

_Supplier:_ [Novoacril](https://novoacril.cl/acrilico-trasparente)

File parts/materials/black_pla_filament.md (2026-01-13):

# Black PLA filament

Certain parts specifically require black filament.

_Supplier:_ [Esun](https://www.esun3d.com/)

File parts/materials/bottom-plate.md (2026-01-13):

# Bottom plate

Download [bottom-plate.dxf](laser-cut/bottom-plate.dxf)



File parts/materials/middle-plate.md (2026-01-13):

# Middle plate

Download [middle-plate.dxf](laser-cut/middle-plate.dxf)



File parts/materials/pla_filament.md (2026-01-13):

# PLA filament

The microscope design has been tested using PLA filament only. PLA is the most common 3D printer filament. It is easy to use and has low part shrinkage. We have found that the lifetime of the microscope is affected by the quality of the PLA filament, as such we recommend buying high quality filament and storing the filament in a dry sealed container before printing.

_Supplier:_ [Esun](https://www.esun3d.com/)

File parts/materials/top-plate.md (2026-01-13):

# Top plate

Download [top-plate.dxf](laser-cut/top-plate.dxf)



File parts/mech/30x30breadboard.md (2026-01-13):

---
PartData:
    Specs:
        Type: Metric
        Length: 300x300mm
        Material: Aluminium
        Supplier:  -[Thorlabs](https://www.thorlabs.com/thorproduct.cfm?partnumber=MB3030/M)
---

# Breadboard



It is a rigid, machined metal platform, which in this case is made of aluminum, that serves as a base for mounting optical, electronic, or mechanical components in experiments, testing setups, or prototyping systems.

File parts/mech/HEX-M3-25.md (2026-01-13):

---
PartData:
    Specs:
        Type: M3
        Length: 25mm
        Material: Stainless steel
        Tool needed: Spanner
        Supplier:  -[Aliexpress](aliexpress.com/item/1005008724152831.html)
---

# M3 HEX screw



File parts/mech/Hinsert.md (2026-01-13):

---
PartData:
    Specs:
        Type: M3
        Diameter: 4mm aprox.
        Material: Brass
        Tool needed: Soldering iron
        Supplier: -[Aliexpress](https://es.aliexpress.com/item/1005005220632314.html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)

---
# Heat inserts



Threaded insert used for creating secure connections in materials. Heat is applied to soften the material, allowing the insert to be pressed or screwed in. It provides a strong threaded connection in materials like plastic, acrylic and wood. Used in industries like electronics, automotive, and aerospace.

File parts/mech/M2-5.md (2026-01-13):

---
PartData:
    Specs:
        Type: M2
        Length: 5mm
        Material: Stainless steel
        Tool needed: HEX key
        Supplier:  -[Pernos kim](https://pernos-kim.negocio.site/)
---
# Screw

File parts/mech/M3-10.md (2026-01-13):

---
PartData:
    Specs:
        Type: M3
        Length: 10mm
        Material: Stainless steel
        Tool needed: HEX key
        Supplier:  -[Pernos kim](https://pernos-kim.negocio.site/)

---
# Screw

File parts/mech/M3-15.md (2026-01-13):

---
PartData:
    Specs:
        Type: M3
        Length: 15mm
        Material: Stainless steel
        Tool needed: HEX key
        Supplier:  -[Pernos kim](https://pernos-kim.negocio.site/)
---
# Screw

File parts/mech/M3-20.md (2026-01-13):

---
PartData:
    Specs:
        Type: M3
        Length: 20mm
        Material: Stainless steel
        Tool needed: HEX key

---
# Screw

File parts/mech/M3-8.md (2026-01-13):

---
PartData:
    Specs:
        Type: M3
        Length: 8mm
        Material: Stainless steel
        Tool needed: HEX key
        Supplier:  -[Pernos kim](https://pernos-kim.negocio.site/)
---
# Screw

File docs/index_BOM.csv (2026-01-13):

Name in documentation | Category | Qty | Full Name | Notes
2.5mm Ball-end Allen key | tool | None
300x300mm Breadboard | mech | 1 | Breadboard
M3 x 25mm HEX screw | mech | None | M3 HEX screw
M6 x 16mm inner screw | mech | 6 | M6 x 16 inner screw
Nut | mech | None

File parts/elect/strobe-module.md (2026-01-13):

# Strobe Module





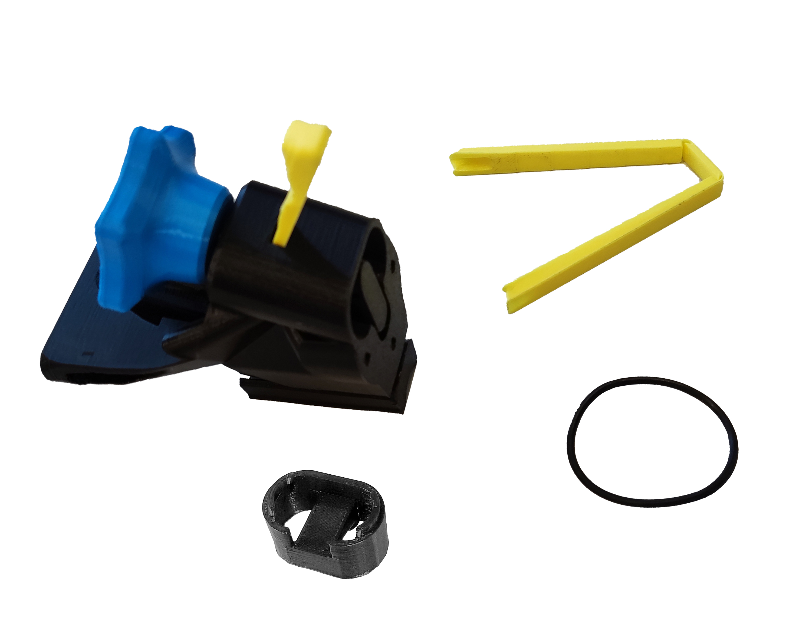
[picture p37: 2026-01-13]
docs/images/band_insertion_parts.jpg

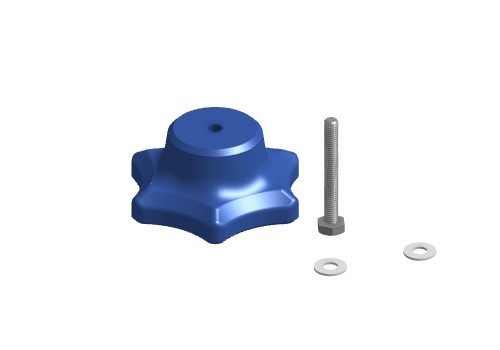
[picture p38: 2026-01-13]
docs/images/thumbwheel_parts.jpg

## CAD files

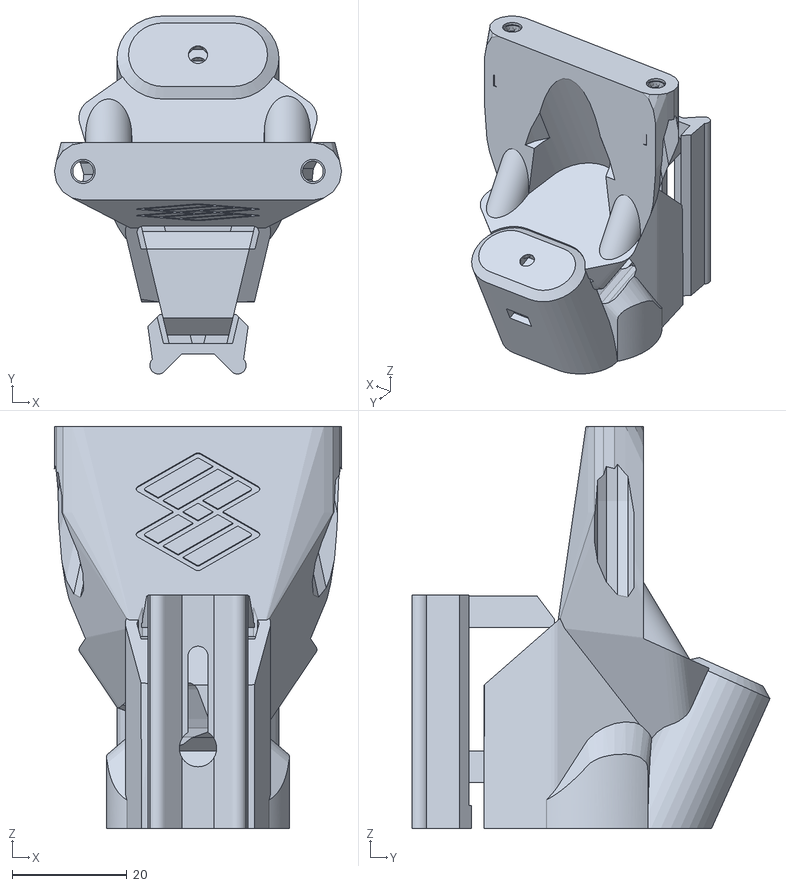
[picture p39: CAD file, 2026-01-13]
docs/models/focusing-assembly.stl
50.0 x 62.3 x 70.0

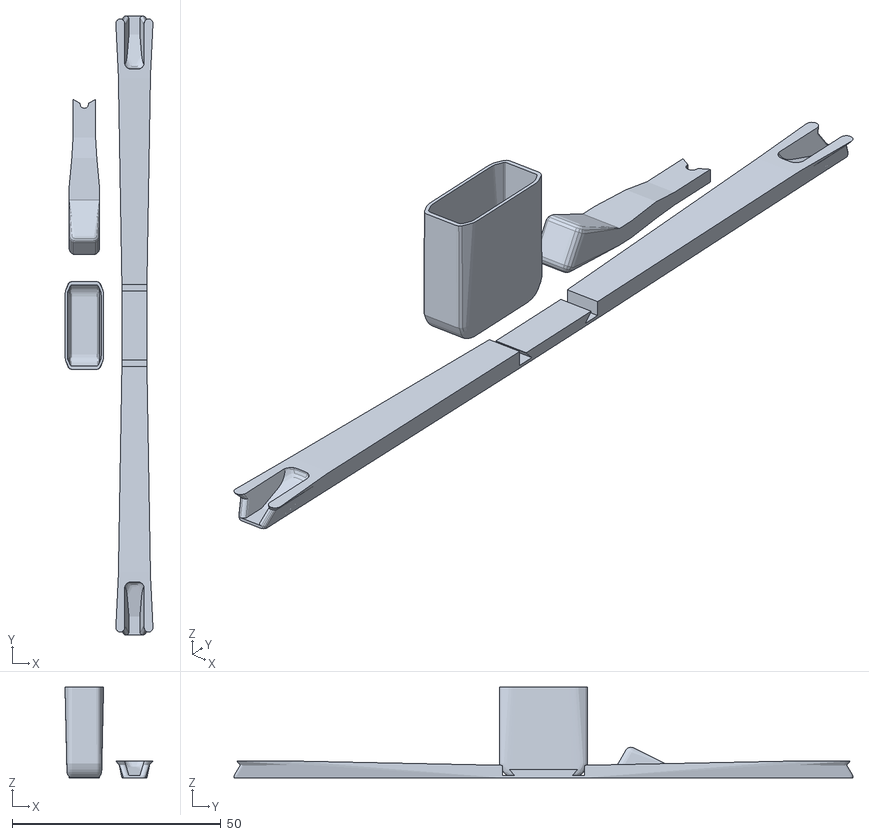
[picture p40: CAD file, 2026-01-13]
docs/models/actuator-assembly-tools.stl
21.1 x 148.2 x 21.7

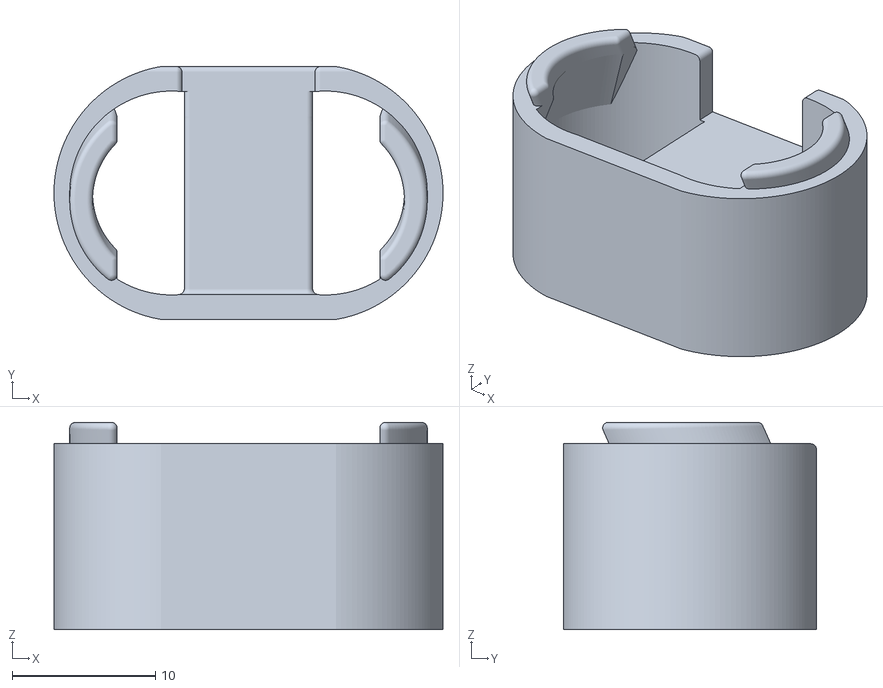
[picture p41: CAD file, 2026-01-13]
docs/models/z_foot.stl
27.2 x 17.7 x 14.5

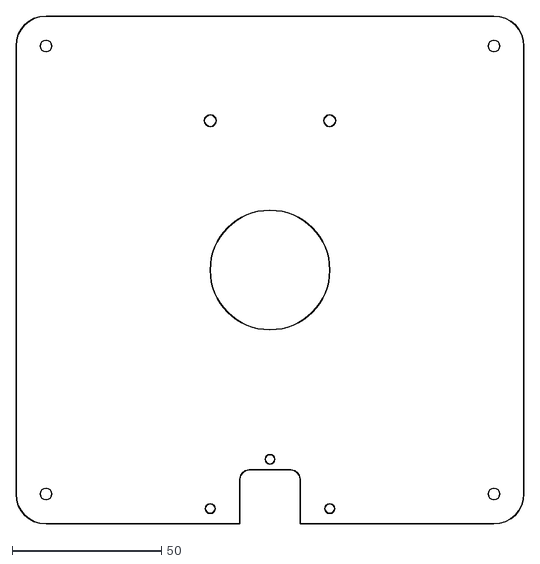
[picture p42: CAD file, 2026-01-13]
docs/parts/materials/laser-cut/top-plate.dxf
170.0 x 170.0

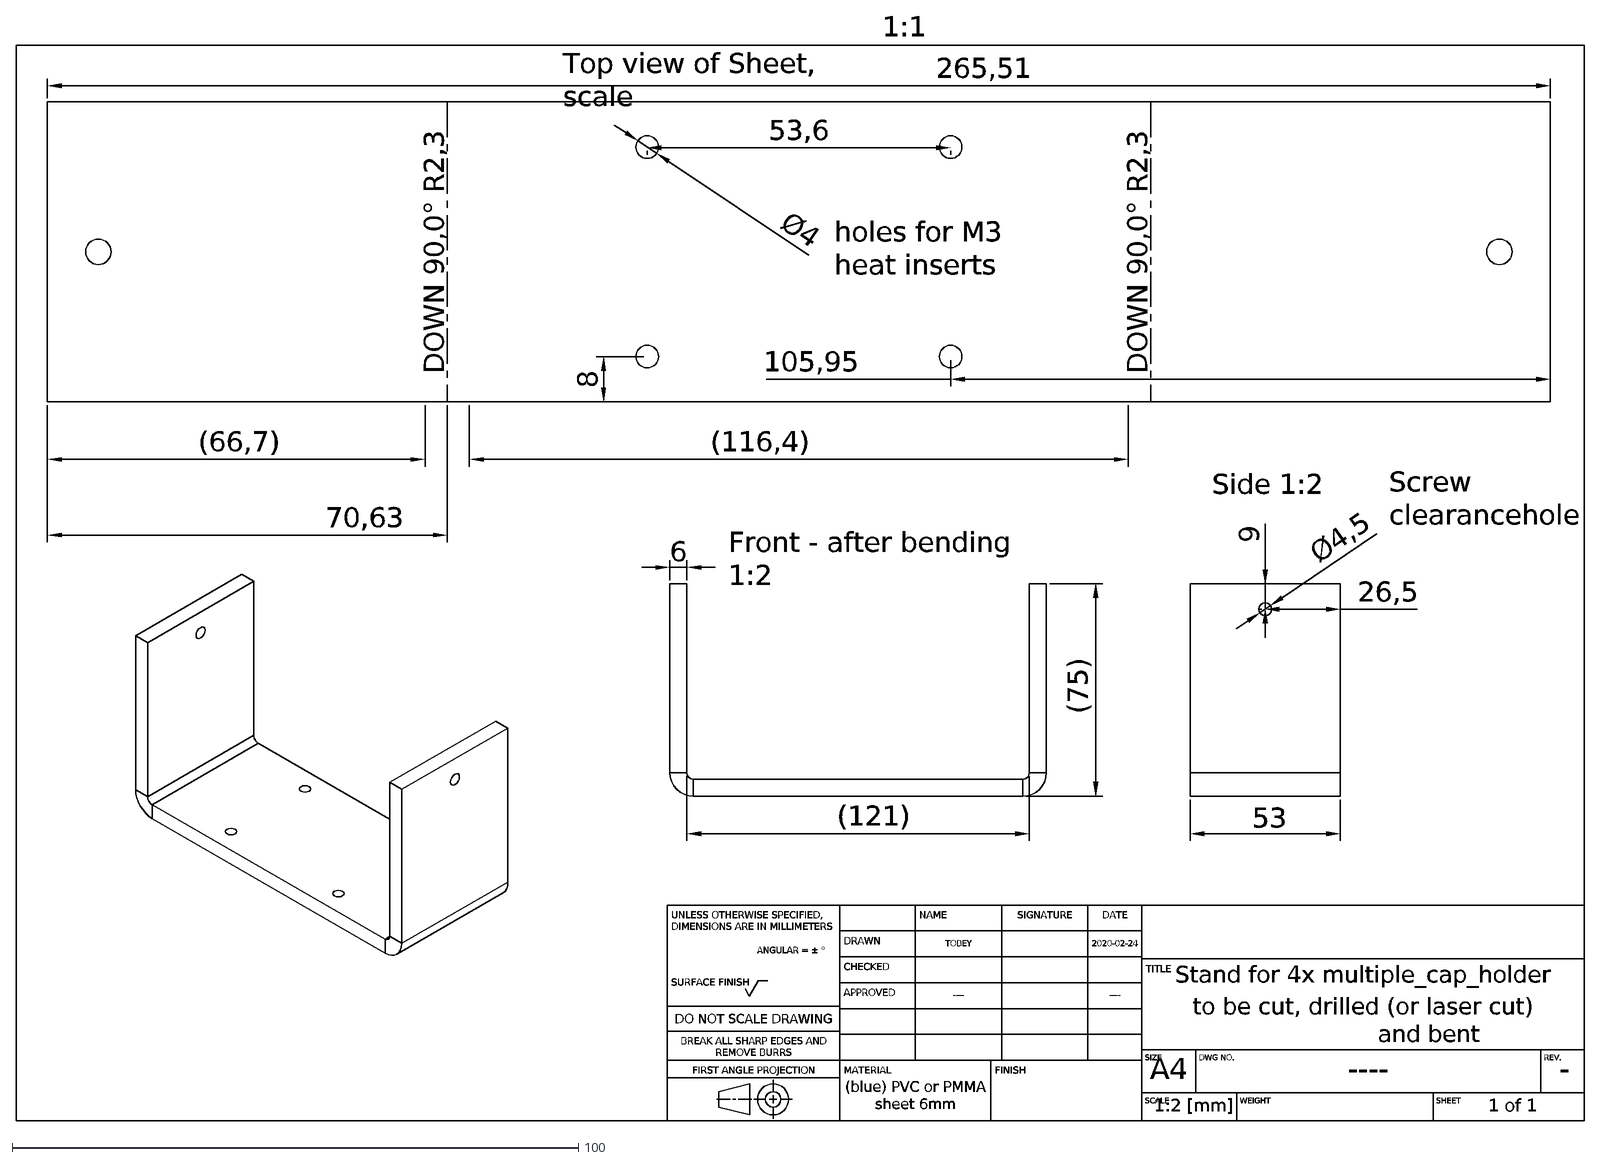
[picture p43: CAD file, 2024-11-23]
hardware-modules/module_sample_reservoirs/manufacturing_files/Drawing of stand 4x (borader, thicker).dxf
UNLESS OTHERWISE SPECIFIED, DIMENSIONS ARE IN MILLIMETERS
ANGULAR = ± °
SURFACE FINISH
DO NOT SCALE DRAWING
BREAK ALL SHARP EDGES AND REMOVE BURRS
FIRST ANGLE PROJECTION
SIGNATURE
NAME
DATE
DRAWN
TOBEY
2020-02-24
CHECKED
APPROVED
----
MATERIAL
(blue) PVC or PMMA sheet 6mm
FINISH
TITLE
Stand for 4x multiple_cap_holder
to be cut, drilled (or laser cut) and bent
SIZE
A4
DWG NO.
REV.
-
SCALE
1:2 [mm]
WEIGHT
SHEET
1 of 1
(75)
(121)
Front - after bending 1:2
Ø4,5
9
Side 1:2
1:1
Top view of Sheet, scale
Screw clearance hole
(66,7)
(116,4)
70,63
265,51
53
26,5
Ø4
8
105,95
53,6
holes for M3 heat inserts
6
DOWN 90,0° R2,3

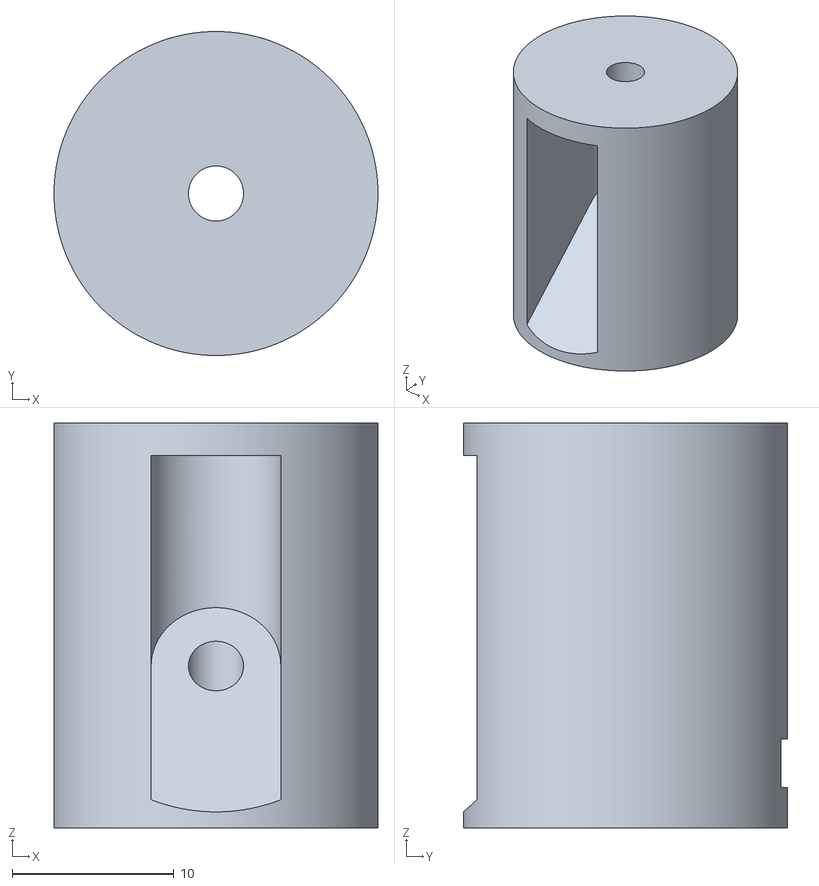
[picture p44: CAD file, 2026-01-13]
models/standoff-S.stl
20.0 x 20.0 x 25.0

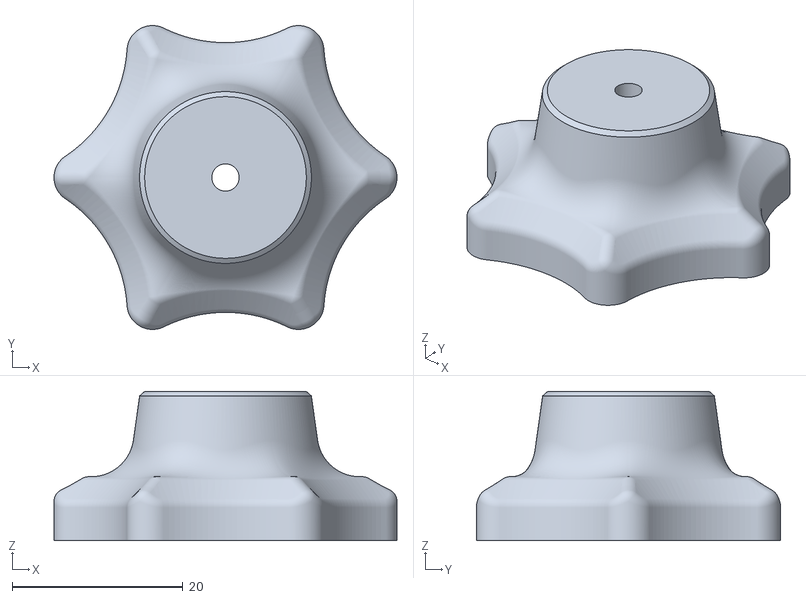
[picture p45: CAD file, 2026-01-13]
docs/models/thumbwheel.stl
40.2 x 35.6 x 17.5

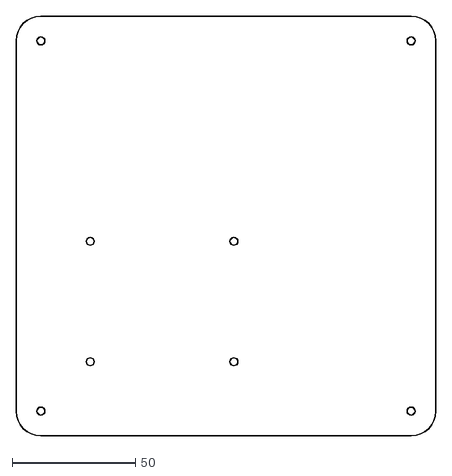
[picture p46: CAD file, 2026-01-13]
docs/parts/materials/laser-cut/bottom-plate.dxf
170.0 x 170.0

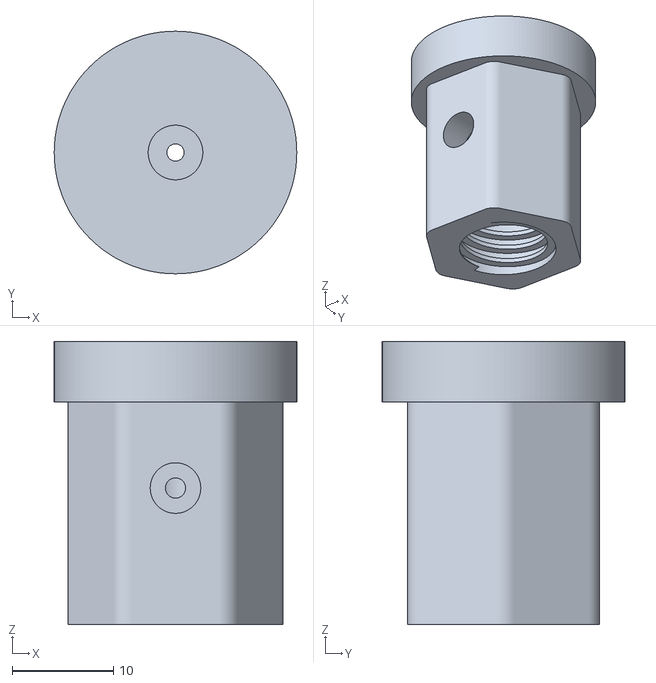
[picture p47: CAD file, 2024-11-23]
hardware-modules/module_sample_reservoirs/manufacturing_files/Individual_cap.stl
24.0 x 24.0 x 28.0

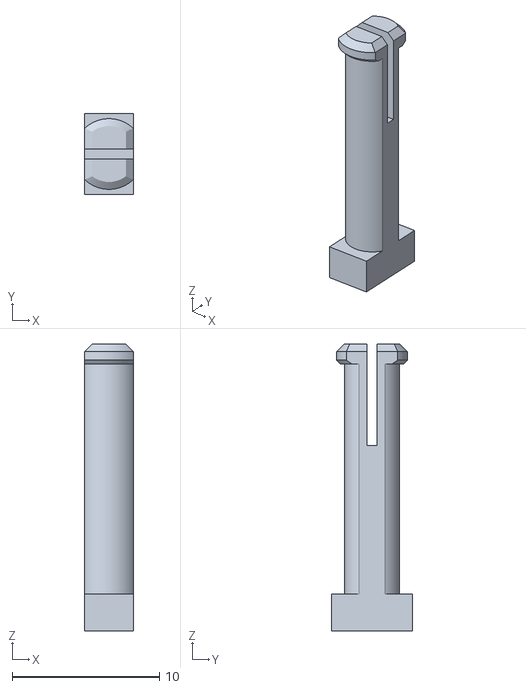
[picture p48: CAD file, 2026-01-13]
models/arm-pin.stl
3.30 x 5.50 x 19.5

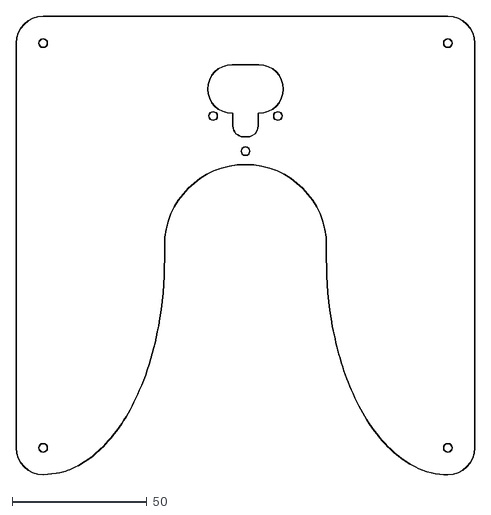
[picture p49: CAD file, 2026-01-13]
docs/parts/materials/laser-cut/middle-plate.dxf
170.0 x 170.0

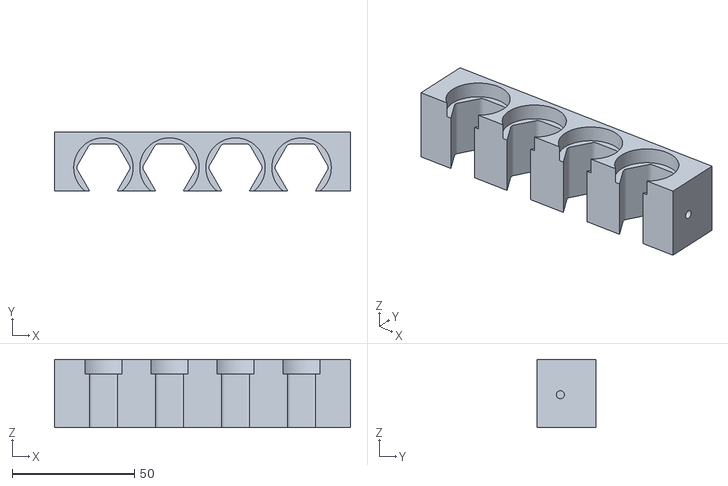
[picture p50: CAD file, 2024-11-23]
hardware-modules/module_sample_reservoirs/manufacturing_files/Multiple_cap_holder.stl
121.0 x 24.0 x 28.0

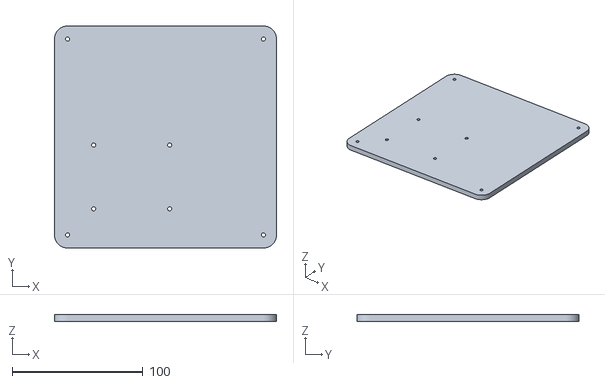
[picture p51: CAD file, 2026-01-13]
models/Holders-bottom-plate.stl
170.0 x 170.0 x 5.00

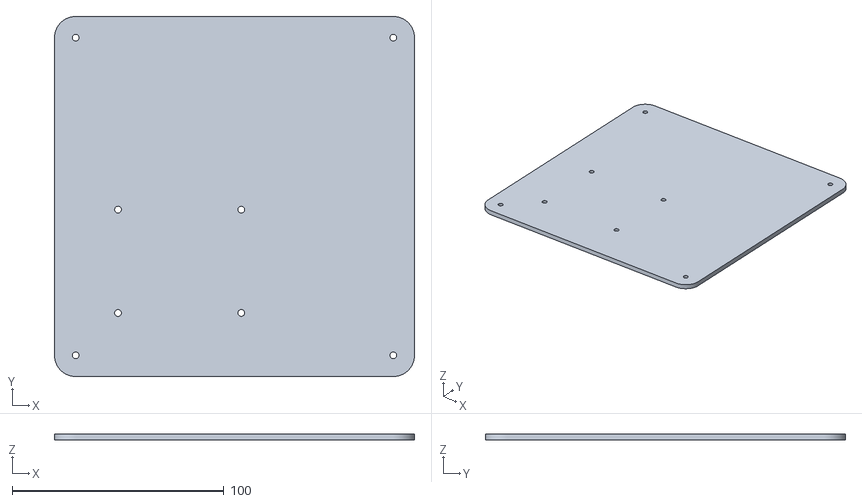
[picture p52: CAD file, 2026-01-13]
models/3D-Bottom-plate.stl
170.0 x 170.0 x 3.00

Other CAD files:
hardware-modules/module_sample_reservoirs/design_files/Parts for Microfluidic_manifold_for_pressure_vials - Individual_cap.sldprt
hardware-modules/module_sample_reservoirs/design_files/Multiple_cap_holder.sldprt
models/Holders-middle-plate.stl
models/top-plate.stl
models/Holders-top-plate.stl
models/camera-platform.stl
models/foot-M.stl
models/illumination-base.stl
models/illumination-slider.stl
models/illumination-thumbscrew.stl
models/led-arm.stl
models/led-cover.stl
models/leg_test.stl
models/lens-spacer.stl
models/middle-plate.stl
models/screencase.stl
models/spacer-11mm.stl
models/spacer-4mm.stl
models/standoff-M.stl

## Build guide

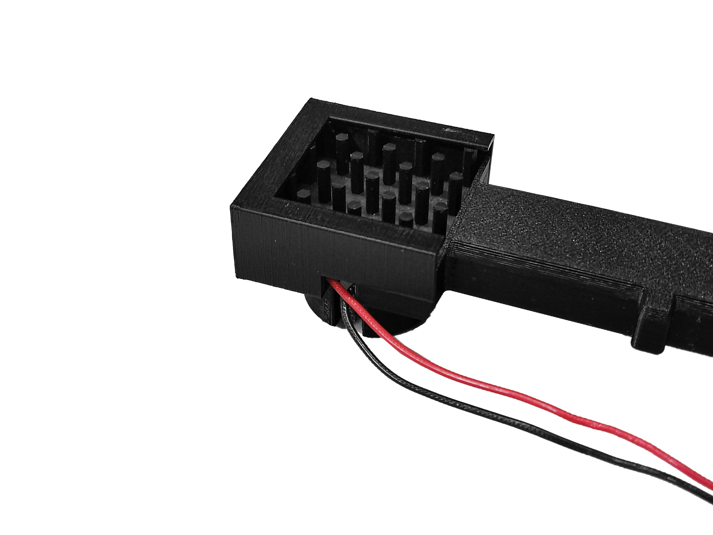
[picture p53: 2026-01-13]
images/led-assembly-arm_2.jpg

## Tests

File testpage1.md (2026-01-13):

#Assemble the base
{{BOM}}

[M6 x 16mm inner screw]: parts/mech/M6-16i.md "{cat:mech}"
[M3 x 25mm HEX screw]: parts/mech/HEX-M3-25.md "{cat:mech}"
[Nut]: parts/mech/nuts.md "{cat:mech}"
[300x300mm Breadboard]:parts/mech/30x30breadboard.md "{cat:mech}"
[2.5mm Ball-end Allen key]: parts/tools/2.5mmBallEndAllenKey.md "{cat:tool}"

## Put screws into the widget {pagestep}

* Get 6 [M6 x 16mm inner screw]{Qty: 6}s and use them to get the 4 resin-filled legs and the 2 resin-filled thin legs into the 300x300mm [breadboard][300x300mm Breadboard](https://www.thorlabs.com/thorproduct.cfm?partnumber=MB3030/M){Qty:1}

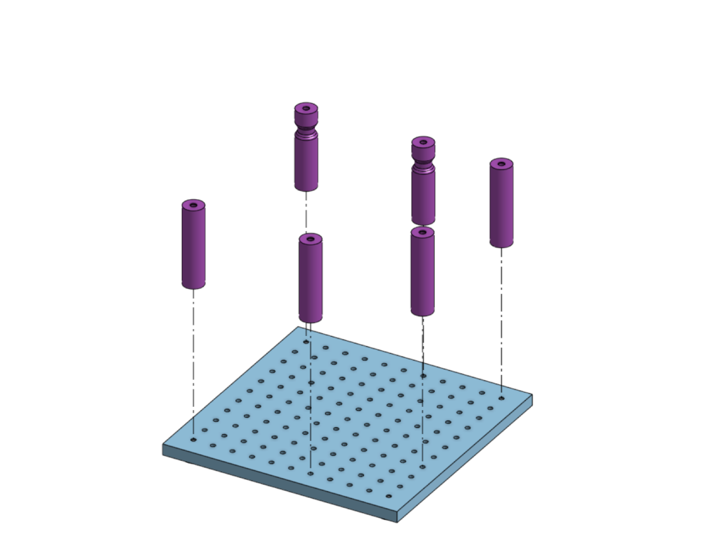
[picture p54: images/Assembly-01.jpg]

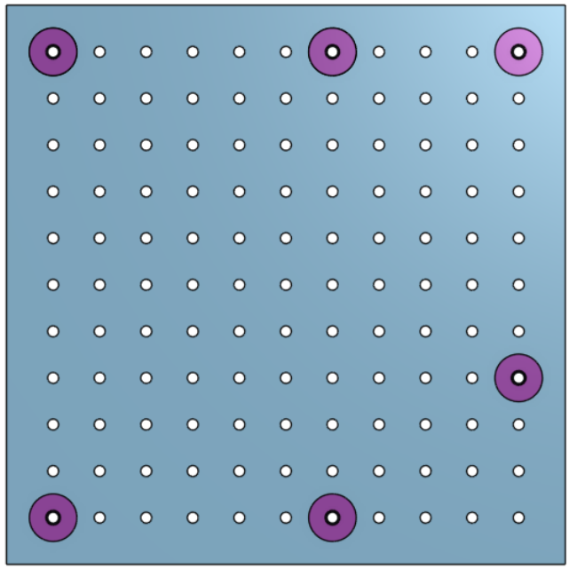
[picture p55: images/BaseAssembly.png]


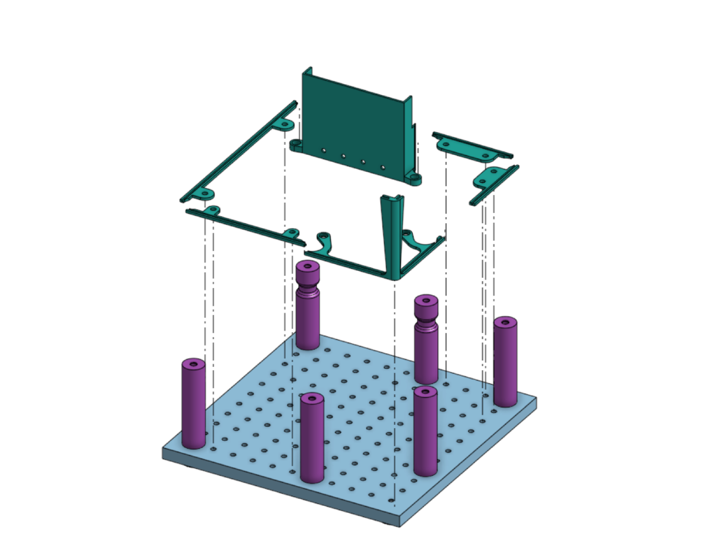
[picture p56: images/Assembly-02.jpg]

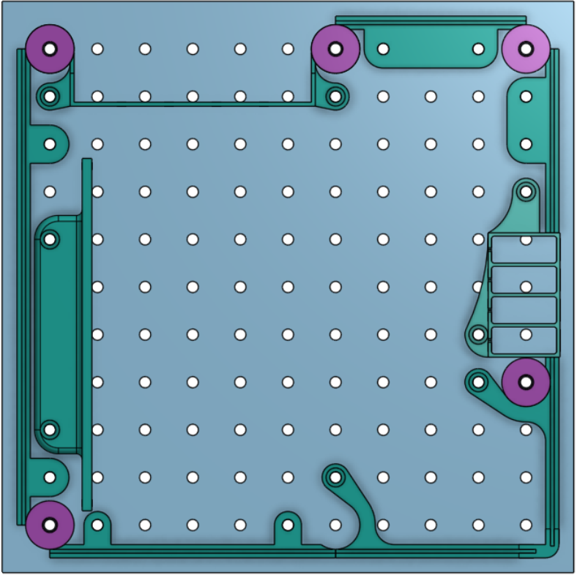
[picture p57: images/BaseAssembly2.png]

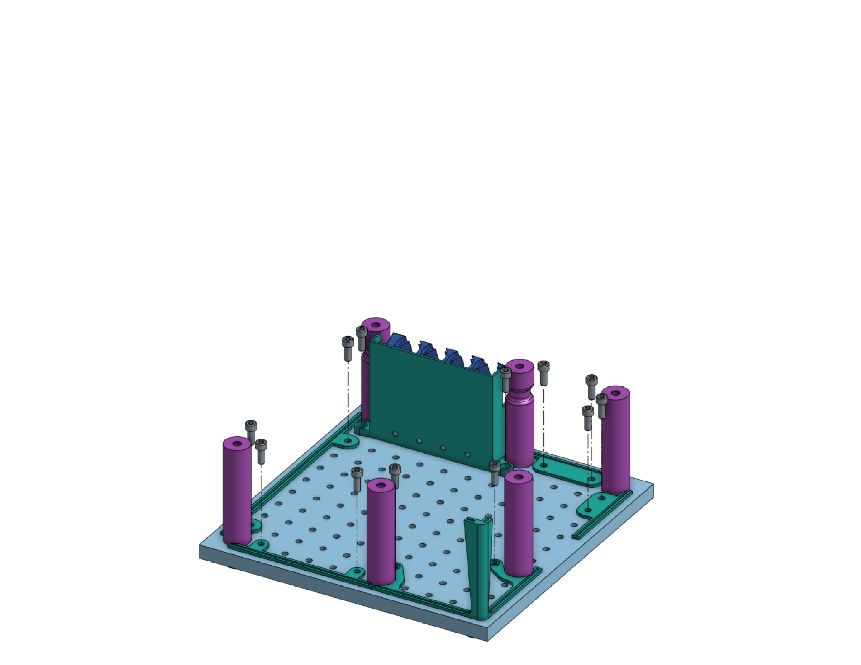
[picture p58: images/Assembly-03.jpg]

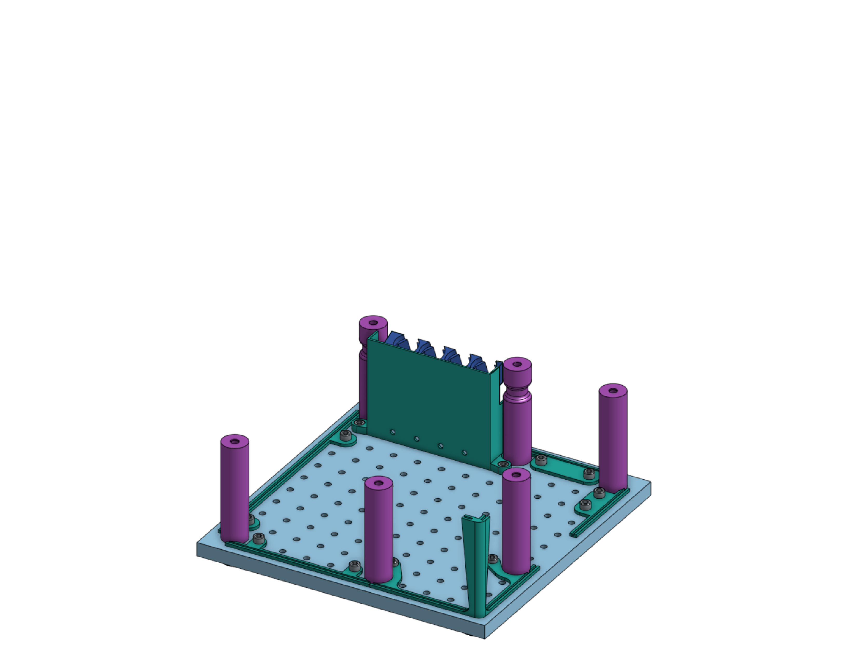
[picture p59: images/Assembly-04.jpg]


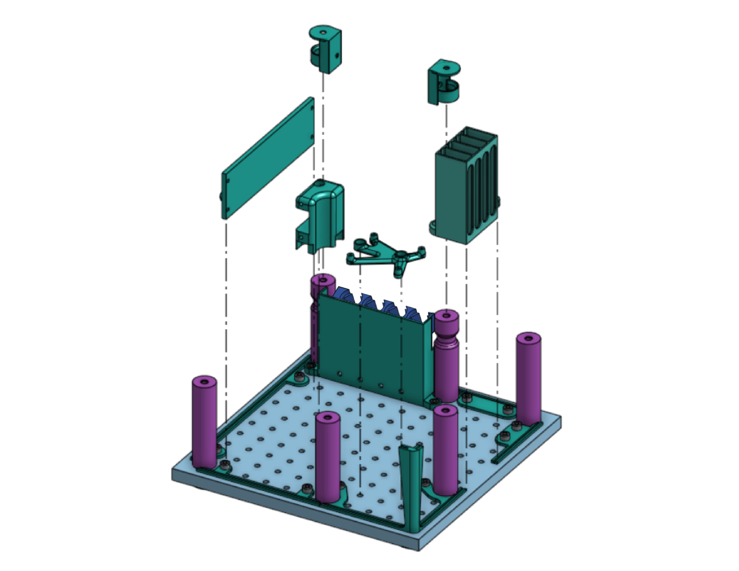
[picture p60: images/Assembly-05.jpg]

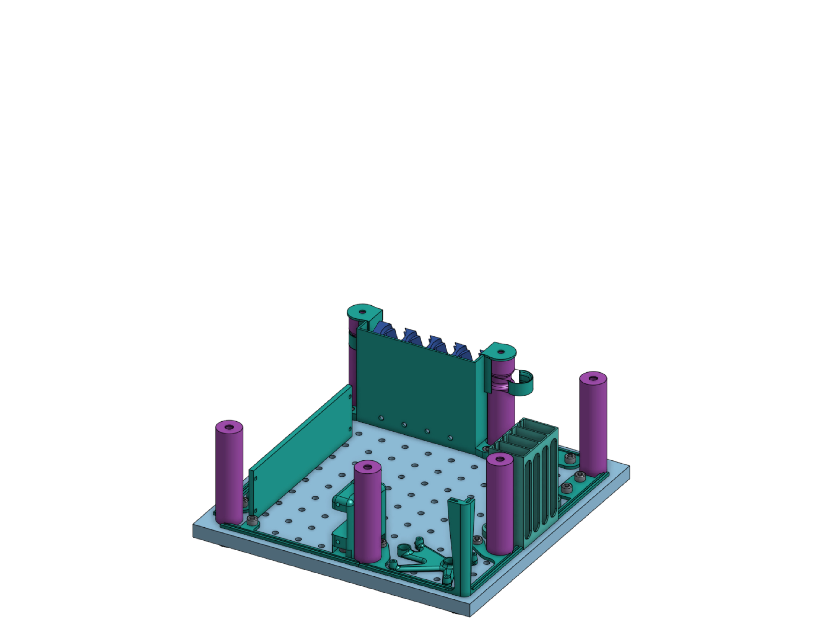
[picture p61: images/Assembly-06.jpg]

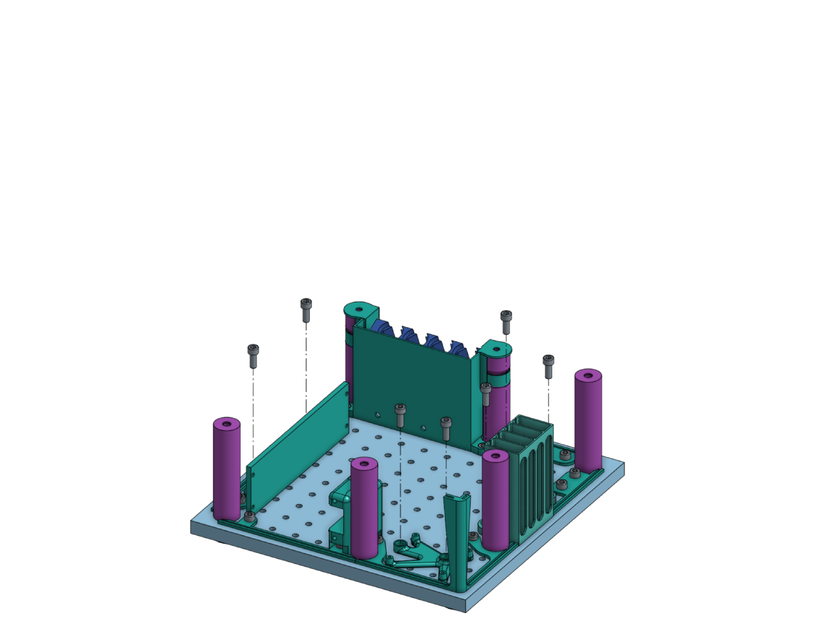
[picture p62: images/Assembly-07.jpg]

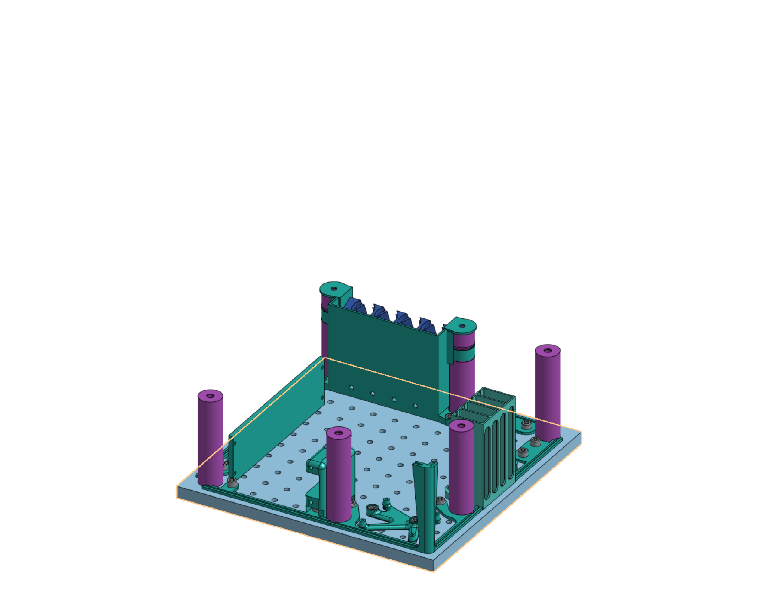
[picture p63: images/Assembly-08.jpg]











## Put more screws into the widget {pagestep}

* Find thgug
* hgfr

>i **Please Note:** 
>i This site is under construction.

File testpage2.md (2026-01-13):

# Prepare the parts

####Here you can make, adapt and download all the important components 

|||
|---|---|
|[Resin-filled legs](resin-legs.md)|[Camera Base](Camera-Base-With-Mirror.md)|
||
|[Liquids Holder](Liquids-Holder.md) | [Focus Mechanism](focus-mechanism.md)
|  |

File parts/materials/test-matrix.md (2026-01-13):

# Test Matrix

Download [test-matrix.pdf](laser-cut/test-matrix-2023.pdf)



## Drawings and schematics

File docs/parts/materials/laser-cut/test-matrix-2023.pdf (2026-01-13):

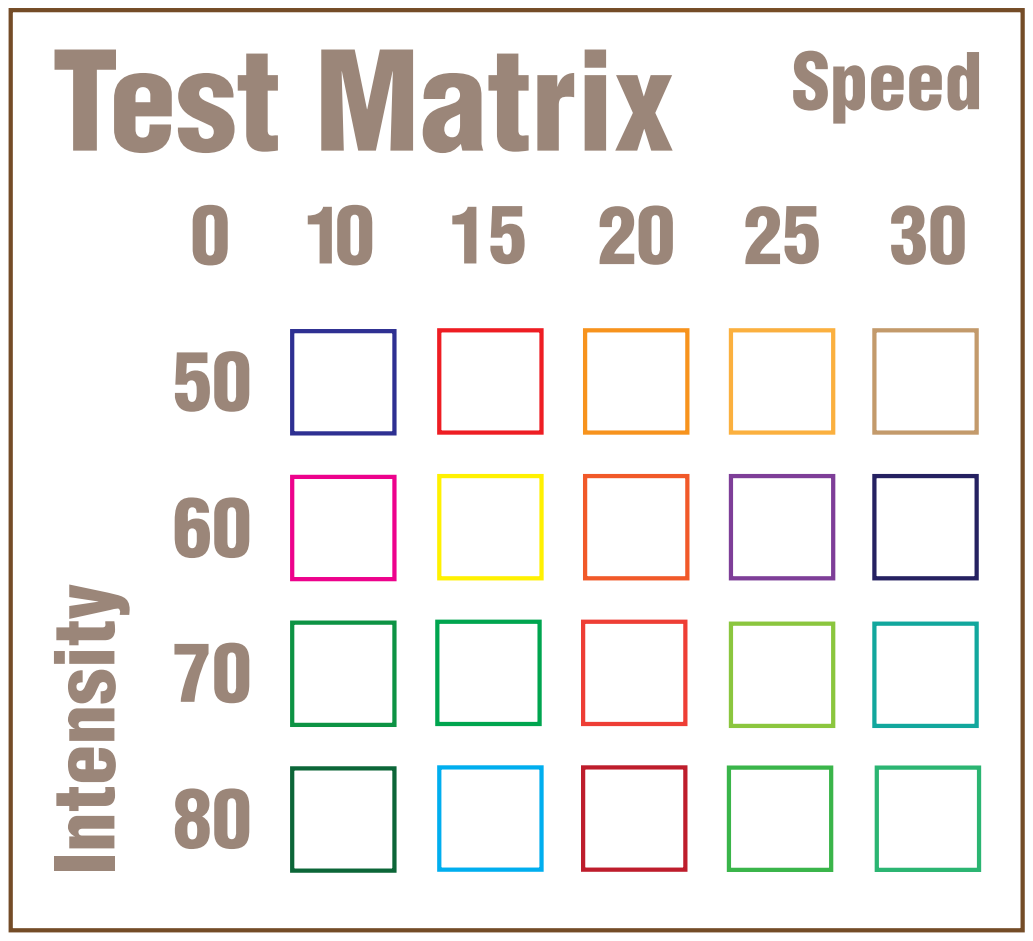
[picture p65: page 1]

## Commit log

2024-11-23 move modules from controller repo
    [Drawing of stand 4x (borader, thicker).dxf, Individual_cap.stl, Multiple_cap_holder.sldprt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]
2024-12-30 Deploying to main from @ 07615b58de2bee3f3fa9748aba6c72f459815577 🚀
    [index_BOM.csv]
2024-12-30 Deploying to main from @ 6d8d7c67431feda1ebe6add28cd8fe633bedd2a3 🚀
    [index_BOM.csv]
2024-12-30 Remove files
    [index_BOM.csv]
2024-12-30 Test MkDocs site
    [index_BOM.csv]
2026-01-13 Add GitBuilding documentation draft
    [3D-Bottom-plate.stl, Drawing of stand 4x (borader, thicker).dxf, Holders-bottom-plate.stl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]
2026-01-13 Update folder configuration
    [actuator-assembly-tools.stl, focusing-assembly.stl, thumbwheel.stl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]
2026-01-13 Update docs folder
    [bottom-plate.dxf, index_BOM.csv, middle-plate.dxf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]
